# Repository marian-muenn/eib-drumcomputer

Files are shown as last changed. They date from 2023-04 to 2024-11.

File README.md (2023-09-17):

# EIB Drumcomputer

## Projektstruktur
~~~
Das Projekt ist wie folgt strukturiert:
  ./3d/                                                 Dateien für den 3D-Druck
  ./3d/abstandshalter_stromversorgung/                  Abstandhalter zur Montage der Stromversorgung
  ./3d/blindplatte/                                     Blindplatten in diversen Breiten
  ./3d/midi/                                            Frontplatte des MIDI-Interface-Moduls
  ./3d/modul-2-poti/                                    Frontplatte für Drummodule mit 2 Potentiometern
  ./3d/modul_3_poti/                                    Frontplatte für Drummodule mit 3 Potentiometern
  ./3d/winkel/                                          Winkel zur Platinenmontage
  ./doku/                                               Montageanleitung, Bauteillisten, Datenblätter und Spezifikationen
  ./kicad/                                              Platinenentwürfe
  ./kicad/midi-interface                                Platine des MIDI-Interface-Moduls
  ./kicad/line-out                                      Schaltplan des Line-Out Moduls
  ./kicad/klangerzeugung                                Platine zur Klangerzeugung
  ./ltspice/                                            Simulationen
  ./src                                                 Programmcode
  ./tex                                                 Latex Dokumente (Beleg und Montageanleitung)
~~~

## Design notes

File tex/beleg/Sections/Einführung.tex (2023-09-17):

\section{Einführung}

Dieses Projekt widmet sich der Umsetzung eines Drumcomputers, einem elektronischen Musikinstrument, das die Erzeugung und Steuerung perkussiver Klänge ermöglicht. Ein Drumcomputer bietet die Möglichkeit, individuelle Rhythmen zu generieren und abzuspielen, was beispielsweise als Begleitung für Solokünstler von großem Nutzen ist. Der von uns entwickelte Drumcomputer kombiniert analoge Klangerzeugung mit moderner Digitaltechnologie, die eine Steuerung der Klänge über einen Computer ermöglicht. Das Projekt beinhaltet Themen der Digitalen Datenkommunikation, und der Analogen Schaltungstechnik.

Die Grundlage für die Klangerzeugung dieses Projekts beruht auf den Anfängen der elektronischen Musik in den 1970er und 80er Jahren. Es werden insgesamt acht verschiedene Klänge erzeugt, die mithilfe analoger Schwingkreise realisiert werden: Bassdrum (Große Trommel), zwei Snaredrums (Schnarrtrommeln), Cymbal (Becken), Clave (Klanghölzer), Maracas (Rumba-Rasseln) und zwei Congas (lateinamerikanische Trommeln). Diese Klänge können entweder einzeln über einen Taster abgespielt oder vom Mikrocontroller gesteuert werden. Der Mikrocontroller empfängt Signale über die MIDI-Schnittstelle und nutzt diese zur Steuerung der Klänge. MIDI ist der \enquote{Industriestandard für den Austausch musikalischer Steuerinformationen zwischen elektronischen Instrumenten} \cite{wiki_midi} und ermöglicht die Integration der Klänge in die Struktur anderer elektronischer Klangsysteme.

Das Gerät ist im Eurorack-Format konzipiert, um eine nahtlose Integration zu gewährleisten. Eurorack ist ein standardisiertes Format für den Bau von Modulen für modulare Synthesizer. Im folgenden Abschnitt wird eine kurze Einführung in modulare Synthesizer gegeben, um das Gesamtprojekt besser zu verstehen und den Kontext zu erläutern.

\subsection{Einführung modularer Synthesizer}

\begin{figure}[H]
    \centering
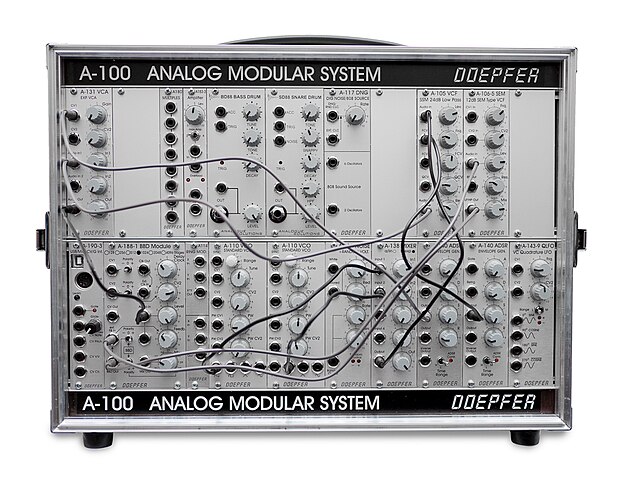
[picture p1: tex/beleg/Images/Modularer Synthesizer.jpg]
    
    \caption[Modularer Synthesizer]{Modularer Synthesizer \cite{wiki_eurorack}}
    \label{fig:Modularer Synthesizer}
\end{figure}

Modulare Synthesizer repräsentieren eine Kategorie von elektronischen Musikinstrumenten, die aufgrund ihrer modularen Struktur eine umfassende Kontrolle über die Klanggenerierung ermöglichen. Der Klang, der schließlich über einen Lautsprecher wiedergegeben wird, setzt sich aus vielfältigen Komponenten zusammen, die in einzelne Module unterteilt sind. 

Die Modularität dieser Synthesizer ermöglicht den Austausch von Modulen sowie die Integration neuer Module. Jedes Modul verfügt über individuelle Parameter, die auch von anderen Modulen beeinflusst werden können. Ein konkretes Beispiel hierfür ist der Voltage-Controlled-Filter (kurz VCF), der durch externe Signale gesteuert werden kann.

Die Verbindung zwischen den einzelnen Modulen erfolgt mithilfe von Kabeln. Jedes Modul verfügt über Ein- und Ausgänge, die den modularen Aufbau ermöglichen und eine flexible Signalverarbeitung ermöglichen.

Das in diesem Projekt entwickelte modulare Drumcomputer-System wurde konzipiert, um die unabhängige Bearbeitung der verschiedenen Klangkomponenten zu ermöglichen. Dadurch können die Klänge separat voneinander verändert und angepasst werden.

Wie bereits in der Einleitung erwähnt, wurde dieses Projekt gemäß dem Eurorack-Standard entwickelt. Das Eurorack stellt eine Stromversorgung für alle Module bereit, wobei die Versorgungsspannungen für die Module bei +12 V, -12 V und +5 V liegen. Der Standard besagt, dass für Trigger Signale 5 V vorgesehen sind. Audio Signale besitzen eine 10 Volt Peak-to-Peak Spannung, für einen besseren Rauschabstand. Zusätzlich sind Pins für Gate- und Steuerspannung (Control Voltage) vorhanden, jedoch werden diese in diesem Projekt nicht verwendet.

%Signale erklären: Gate, Trigger, Control Voltage, Audio
% kurz erläutern, dass auch die bauform der module standardisiert ist

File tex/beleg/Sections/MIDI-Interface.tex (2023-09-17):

\section{MIDI-Interface}
\subsection{Der MIDI Standard}
Die Programmierung des Drumcomputers mit Rythmen soll extern erfolgen. 
Dadurch können bestehende Soft- und Hardware genutzt werden und die Interoperabilität mit anderem Musikequipment ist gegeben.

Dazu wird der Industriestandard MIDI (Music Instrument Digital Interface) genutzt.
Der MIDI-Standard entstand in den 80ger Jahren um Klangerzeuger wie Synthesizer, Keyboards und Drumcomputer sowie Steuergeräte wie Tastaturen miteinander kommunizieren zu lassen.

Auf diese Weise können mit einer Tastatur mehrere Klangerzeuger (Expander) angesprochen werden, was eine erhebliche Kosten und Raumersparnis für Studios und Musiker zur Folge hatte.

Verschiedenste Parameter wie Note, Anschlaggeschwindigkeit, Pedalsignale aber auch allgemeine Kontrollsignale können über MIDI übertragen werden. Aber auch Regleränderungen an einem Klangerzeuger können über MIDI aufgezeichnet und in einem Sequencer oder Computerprogramm wiedergegeben werden.
MIDI verfügt über 16 Kanäle, sodass bis zu 16 mit MIDI-Kabeln verkette Geräte einzeln angesprochen werden können.

Mit dem Aufkommen von Computerprogrammen zur Musikproduktion hielt MIDI auch erstmals Einzug in die Computerwelt. Mithilfe von sogenannten Systemexklusiven Midi-Befehlen können Instrumentenhersteller auch Firmwareupdates über MIDI implementieren.

\subsection{Elektrische Spezifikationen}
Die MIDI Übertragung erfolgt über zweiadrige Leiter mit 5-Pol DIN-Steckverbindern.

Die Datenübertragung wird dabei über eine Stromschleife mit 5mA ausgeführt.
Da Masseschelifen in der Tontechnik oft zu wahrnehmbaren Brummen führen, stellen diese ein Problem dar.
MIDI verhinder Masseschleifen, indem eingehende MIDI-Signale über einen Optokoppler isoliert werden.

Optokoppler sind Bauteile, die eine LED, einen Fotowiderstand und häufig auch einen Transistor in einem Gehäuse vereinen.
In einer Schaltung kann dann mit einem Stromkreis die LED Betrieben werden, in einem Zweiten Stromkreis wird ein proportionales, invertiertes Signal durch Fotowiderstand und Transistor erzeugt. So kann eine Signal zwischen zwei galvanisch getrennten Stromkreisen übertragen werden.

Optional besteht die Möglichkeit, das Signal über einen MIDI-Thru Ausgang an ein weiteres Gerät durchzuschleifen. Dazu wird eine zweite 5 mA Stromschleife hinter dem Optokoppler implementiert und über eine weitere DIN-Buchse ausgegeben.
Auf diese Weise lassen sich bis zu 16 Geräte verketten.
In Abbildung (\ref{fig:schaltplan-midi-inout}) ist die gebräuchliche MIDI-Eingangsschaltung gemäß Spezifikation dargestellt.
\begin{figure}[h]
    \centering
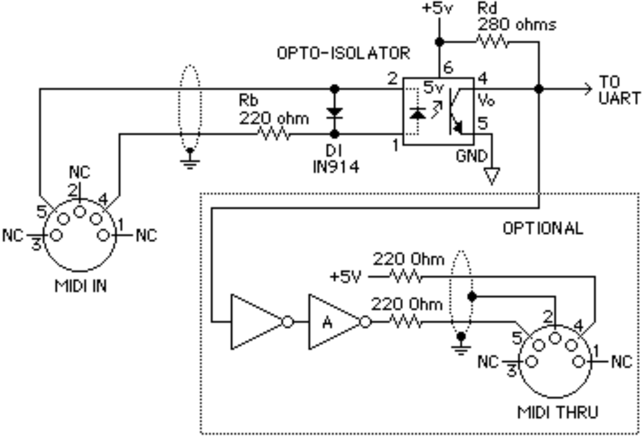
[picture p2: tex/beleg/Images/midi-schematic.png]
    
    \caption{Schaltplan MIDI Eingang \cite[S. 2]{midi}}
    \label{fig:schaltplan-midi-inout}
\end{figure}

Rb dient zur Begrenzung des Stroms, D1 als Schutz vor Verpolung.
Als Optokoppler kommt ein 6n138 zum Einsatz. Rd ist dabei der Pullupwiderstand für das Ausgangssignal. Um das 31250 Baud-Signal trotz des intrinsisch langsamen Optokopplers ohne Verlust der Signalintegrität übertragen zu können, wird ein relativ geringer Pullupwiderstand von 280 Ohm verbaut.

\subsection{MIDI-Befehle}

Ein MIDI Befehl setzt sich aus 3 über eine serielle Verbindung übertragenen Bytes zusammen.
Im ersten Byte wird ein Statuscode übertragen, Bytes 2 und 3 enthalten Daten.
Statusbytes und Datenbytes lassen sich auch anhand des MSB unterscheiden. Bei Statusbytes ist das Most-Significant-Bit auf 1 gesetzt, bei Datenbytes auf 0.
In Tabelle (\ref{table:midi-commands}) sind einige der MIDI-Befehle aufgeschlüsselt.

\ctable[
  maxwidth=\linewidth,
  caption=Midi Befehlsübersicht \cite{wiki_midi},\cite{midi},
  botcap,
  pos=h,
  label=table:midi-commands
  ]{llllX}{}{%
  \FL
Status  & Byte1 & Byte 2    & Aktion        & Beschreibung\ML
0x9n    & 0xkk  & 0xvv      & Note On     & Beginnt das Spielen einer Note kk auf Kanal n mit Anschlagdynamik kk\NN
0x8n    & 0xkk  & 0xvv     & Note Off  &   Beendet das Spielen einer Note kk auf Kanal n mit \enquote{Release Velocity} kk\NN
0xBn 	& 0xcc 	& 0xvv 	     & Control Change &	Ändert den Zustand eines Controllers auf Kanal n (Instrumentenspzifisch) \NN
0xEn 	& 0xvv  & 0xww 	 & Pitch Bending & Ändert die Tonhöhe der gehaltenen Noten, ähnlich wie das Saitenziehen bei einer Gitarre \NN
0xF0…7 	& 0xx 	&           & System exclusive Message & Steuermeldungen, gerätespezifisch, Länge beliebig \NN
\LL}

Um die Datenübertragung zu beschleunigen, darf bei wiederholter Übertragung von Befehlen des gleichen Typs das Statusbyte ausgelassen werden.

Zusätzlich zu den hier genannten Befehlen nutzt MIDI \enquote{Active Sensing}.
Dabei wird im Abstand von 300 ms das Byte \texttt{0b00000001} übertragen.
Wenn diese Übertragung ausbleibt, kann ein lauschendes Gerät einen Ausfall des Übertragungskanals erkennen und das Spielen von Noten beenden.

\subsection{Hardwareentwurf des Midi-Interfaces}
\label{midi-hardwareentwurf}
Um die MIDI-Schnittstelle des Drumcomputers zu implementieren wurde eine Interfacemodul gebaut.
Dieses hat einen MIDI-Eingang sowie 12 Triggersignal-Ausgänge.
Zum Auswerten der Seriellen Midi Kommunikation nutzt das Midi-Modul ein Arduino UNO, das von hinten auf die Platine aufgesteckt wird.

Die Entscheidung für das Arduino fiel, da es bereits vorhanden war, den Anforderungen an die Pin-Anzahl und Systemleistung genügt und der verbaute ATmega328p Microcontroller mit einer Betriebsspannung von 5V läuft. Dadurch können eurorackkompatible Triggersignale ohne Pegelwandler ausgegeben werden.

Für die Eingangsschaltung wurde die Schaltung aus der MIDI-Spezifikation verwendet. Das über den Optokoppler isolierte Signal ist mit dem RX-Pin des Arduinos verbunden.

Zwölf Ausgänge des Mikrocontrollers wurden auf 3.5 mm Mono-Klinkenbuchsen geroutet, damit die Ausgehenden Triggersignale mit Patchkabeln zu die einzelnen Drummodule übertragen werden können.
Dabei besteht die Gefahr, dass mit dem Kabel eine der Betriebsspannungen berührt wird.
Zum Schutz des Microcontrollers wurden daher alle Ausgänge mit 220 Ohm Widerständen gegen Stromspitzen  geschützt.

Schaltpläne und Platinenlayouts finden sich in der beiliegenden Dokumentation.

\subsection{Implementierung der MIDI-Schnittstelle in C}
Die Implementierung des Programmcodes geschah in C, da die Programmierung des ATMega328p in C bereits bekannt war. Teile einer UART-Implementierung lagen aus anderen Lehrveranstaltungen bereits vor, was die Implementierung erleichtert hat.

Der Programmaufbau besteht aus zwei Hauptkomponenten: 
\begin{enumerate}
    \item Einem Zustandsautomaten, der in der Interruptroutine der seriellen Schnittstelle eingehende MIDI-Befehle entgegen nimmt.
    \item Einer periodisch ablaufenden Funktion, die die jeweiligen Ausgänge schaltet.
\end{enumerate}

Der Zustandsautomat der MIDI-Implementierung ist in Abbildung (\ref{fig:sm}) abgebildet.

\begin{figure}[h]
    \centering
    
    \caption{Zustandsautomat der Midi Implementierung}
    \label{fig:sm}
\end{figure}

Da nur Triggersignale generiert werden müssen, ist nur der Note-On Statuscode relevant. Die Ausgänge werden nach 1 ms wieder abgeschaltet, der Note-Off Befehl wird ignoriert.

Das Programm beginnt im Zustand \enquote{ready}.
Beim Empfang eines Note-On-Statuscodes geht der Automat in den Zustand \enquote{note\_on} über.

Beim Eingang des ersten Datenbytes wird in den Zustand \enquote{note\_data1} übergegangen, die über-tragenen Notenwerte werden in einer Variable gespeichert.

Nach der Übertragung des zweiten Datenbytes befindet sich der Automat im Zustand \enquote{note\_data2}.
Der zu schaltende Ausgang wird im Pufferspeicher markiert, die im zweiten Datenbyte übertragenen Velocitydaten sind für den Anwendungfall nicht relevant.

Bei Eingang eines weiteren Datenbytes wird in den Zustand \enquote{note\_data1} übergegangen. Dadurch wird die Übertragung mehrerer Note-On Befehle ohne wiederholung des Status-Bytes ermöglicht.

MIDI-Active-Sense Bytes, die regelmäßig übertragen werden um die Funktion des Datenkanals zu prüfen, werden ignoriert.

Bei Übertragung eines anderen Statusbefehls als Note-On wird in den Zustand \enquote{ready} gewechselt und auf Eingang eines Note-On Befehls gewartet.

In der Hauptschleife der \texttt{main}-Funktion werden die zu schaltenden Ausgänge aktiviert, anschließend wird für eine Millisekunde pausiert. So wird erreicht, dass die Triggersignale für genau eine Millisekunde aktiv sind. 
Dieser Schritt findet in einem Atomic-Block statt, sodass kein Interrupt das Schalten der Ausgänge unterbrechen kann.

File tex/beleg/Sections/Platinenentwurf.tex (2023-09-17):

\section{Platinenentwurf}
In Anbetracht der Tatsache, dass die Realisierung der 8 Klänge aufgrund von 3 verschiedenen Schaltungstypen theoretisch den Einsatz individueller Platinen erfordern würde, wurde ein effizienterer Ansatz gewählt. Anstelle der Produktion von drei separaten Platinen, was mit erheblichen Kosten verbunden wäre, wurden die verschiedenen Platinendesigns integriert, um eine einheitliche Platine zu schaffen, die es ermöglicht, alle individuellen Klänge durch die Anpassung der Bauteilbestückung zu erzeugen.

\begin{figure}[h]
    \centering
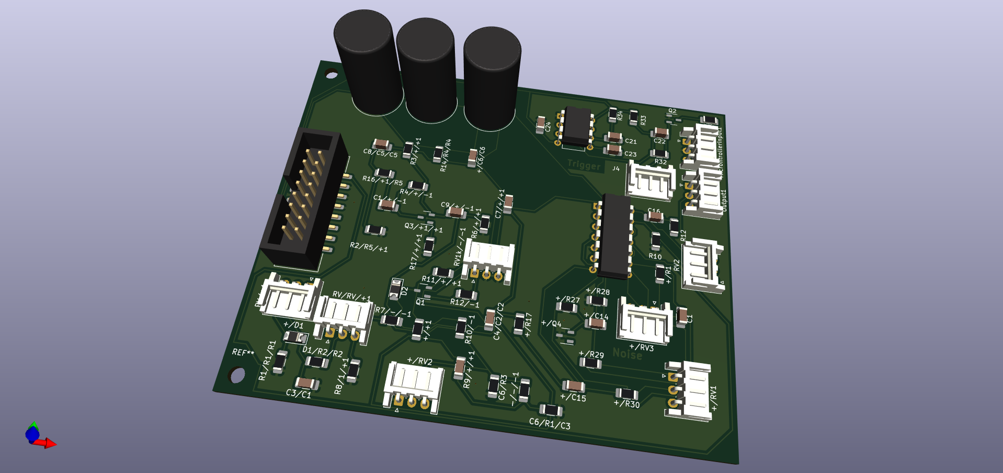
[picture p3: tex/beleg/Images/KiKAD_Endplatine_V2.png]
    
    \caption[Leiterplattenentwurf]{3D-Ansicht der Leiterplatte}
    \label{fig:3D-Ansicht der Leiterplatte}
    \source{KiCad 3D-Ansicht}
\end{figure}

Die Planung und Gestaltung der Platine erfolgte mithilfe von KiCad, einem Open-Source Programm für die Entwicklung von Leiterplattenentwürfen. In Fällen, in denen bereits vorhandene Bauteile wie 3-Pin-Anschlüsse zur Verfügung standen, wurden diese wiederverwendet und entsprechend in das Platinendesign integriert

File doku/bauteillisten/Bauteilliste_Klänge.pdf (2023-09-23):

Bezeichnung Bassdrum | High Bongo High Conga Low Conga | Claves | SnaredrumD Cymbal 1 | Cymbal 2 | maracas | SnareDrum
R1 | 100kΩ | 100kΩ | 100kΩ | 100kΩ | 100kΩ | 100kΩ | 10kΩ | 10kΩ | 10kΩ | 10kΩ
R2 | Diode | Diode | Diode | Diode | Diode | Diode | 1MΩ | 1MΩ | 1MΩ | 1MΩ
R3 | 5kΩ | 5kΩ | 5kΩ | 5kΩ | 5kΩ | 5kΩ | - | - | - | -
R4 | 8.2kΩ | 8.2k | 8.2kΩ | 8.2kΩ | 8.2kΩ | 8.2kΩ | - | - | - | -
R5 | 1MΩ | 1MΩ | 1MΩ | 1MΩ | 1MΩ | 1MΩ | - | - | - | -
R6 | 47kΩ | 27kΩ | 27kΩ | 27kΩ | 27k | 27kΩ | 0Ω | 0Ω | 0Ω | 0Ω
R7 | - | - | - | - | - | - | 470kΩ | 470kΩ | 470kΩ | 470kΩ
R10 | 100Ω | 100Ω | 100Ω | 100Ω | 100Ω | 100Ω | 0Ω | 0Ω | 0Ω | 0Ω
R11 | 22kΩ | 22kΩ | 22kΩ | 22kΩ | 22kΩ | 22kΩ | 56kΩ | 56kΩ | 12k | 20k
R12 | 100kΩ | 100kΩ | 100kΩ | 100kΩ | 39kΩ | 39kΩ | 100kΩ | 100kΩ | 100kΩ | 100kΩ
R13 | - | - | - | - | 56kΩ | 56kΩ | - | - | - | -
R14 | - | - | - | - | 100kΩ | 560kΩ | - | - | - | -
R15 | - | - | - | - | 10kΩ | 10kΩ | - | - | - | -
R16 | - | - | - | - | 330Ω | 2.2kΩ | - | - | - | -
R17 | - | - | - | - | 4.7kΩ | 2.2kΩ | - | - | - | -
R18 | 1kΩ | 1kΩ | 1kΩ | 1kΩ | 1kΩ | 1kΩ | 1kΩ | 1kΩ | 1kΩ | 1kΩ
R19 | 1kΩ | 1kΩ | 1kΩ | 1kΩ | 1kΩ | 1kΩ | 1kΩ | 1kΩ | 1kΩ | 1kΩ
C1 | 10uF | 10uF | 10uF | 10uF | 1uF | 10uF | 180nF | 150nF | 56nF | 56nF
C2 | 68nF | 6.8nF | 6.8nF | 33nF | 1.8nF | 22n | 47nF | 47nF | 10nF | 8.2nF
C3 | 47kΩ | 27kΩ | 27kΩ | 27kΩ | 27k | 27kΩ | - | - | - | -
C4 | 1uF | 1uF | 1uF | 1uF | 1uF | 1uF | - | - | - | -
C5 | 150n | 390nF | 39nF | 82nF | 15nF | 56nF | 1nF | 1nF | 1nF | 1n
C6 | - | - | - | - | - | - | 6.8nF | 6.8nF | 10nF | 3.3nF
C7 | 1uF | 0.47uF | 470nF | 470nF | 1uF | 1uF | 4.7nF | 4.7nF | 4.7nF | 1nF
C8 | - | - | - | - | 1uF | 1uF | - | - | - | -
C9 | - | - | - | - | 8.2nF | 470nF | - | - | - | -
C10 | 1uF | 1uF | 1uF | 1uF | 1uF | 1uF | 1uF | 1uF | 1uF | 1uF
D1 | - | - | - | - | - | - | Diode | Diode | Diode | Diode
D2 | 68nF | 6.8nF | 6.8nF | 33nF | 1.8nF | 22nF | Diode | Diode | Diode | Diode
L1 | - | - | - | - | - | - | 33mH | 33mH | 18mH | 100mH
L2 | - | - | - | - | - | - | - | - | - | 100mH

L3 | - | - | - | - | - | - | - | - | - | 100mH
R21 | - | - | - | - | - | - | 100kΩ | 100kΩ | 100kΩ | 100kΩ
R22 | - | - | - | - | - | - | 100kΩ | 100kΩ | 100kΩ | 100kΩ
R24 | - | - | - | - | - | - | 1kΩ | 1kΩ | 1kΩ | 1kΩ
R25 | - | - | - | - | - | - | 10kΩ | 10kΩ | 10kΩ | 10kΩ
R26 | - | - | - | - | - | - | 1kΩ | 1kΩ | 1kΩ | 1kΩ
C21 | - | - | - | - | - | - | 1uF | 1uF | 1uF | 1uF
C23 | - | - | - | - | - | - | 1uF | 1uF | 1uF | 1uF
R31 | 10kΩ | 10kΩ | 10kΩ | 10kΩ | 10kΩ | 10kΩ | 10kΩ | 10kΩ | 10kΩ | 10kΩ
R32 | 47kΩ | 47kΩ | 47kΩ | 47kΩ | 47kΩ | 47kΩ | 47kΩ | 47kΩ | 47kΩ | 47kΩ
R33 | 220Ω | 220Ω | 220Ω | 220Ω | 220Ω | 220Ω | 220Ω | 220Ω | 220Ω | 220Ω
R34 | 10kΩ | 10kΩ | 10kΩ | 10kΩ | 10kΩ | 10kΩ | 10kΩ | 10kΩ | 10kΩ | 10kΩ
C31 | 100nF | 100nF | 100nF | 100nF | 100nF | 100nF | 100nF | 100nF | 100nF | 100nF
C32 | 10nF | 10nF | 10nF | 10nF | 10nF | 10nF | 10nF | 10nF | 10nF | 10nF
C33 | 10uF | 10uF | 10uF | 10uF | 10uF | 10uF | 10uF | 10uF | 10uF | 10uF
C34 | 100nF | 100nF | 100nF | 100nF | 100nF | 100nF | 100nF | 100nF | 100nF | 100nF
Q1 | NPN | NPN | NPN | NPN | NPN | NPN | NPN | NPN | NPN | NPN
Q2 | - | - | - | - | - | - | NPN | NPN | NPN | NPN
Q3 | NPN | NPN | NPN | NPN | NPN | NPN | NPN | NPN | NPN | NPN
Q4 | - | - | - | - | - | - | NPN | NPN | NPN | NPN
U1 | Ne555 | Ne555 | Ne555 | Ne555 | Ne555 | Ne555 | Ne555 | Ne555 | Ne555 | Ne555
U2 | TL074 | TL074 | TL074 | TL074 | TL074 | TL074 | TL074 | TL074 | TL074 | TL074
RV_Trim | 1kΩ | 1kΩ | 1kΩ | 1kΩ | 1kΩ | 1kΩ | - | - | - | -
RV1 | 10kΩ | 10kΩ | 10kΩ | 10kΩ | 10kΩ | 10kΩ | - | - | - | -
RV2 | 1kΩ | 1kΩ | 1kΩ | 1kΩ | 1kΩ | 1kΩ | 0Ω | 0Ω | 0Ω | 0Ω
RV3 | 50kΩ | 50kΩ | 50kΩ | 50kΩ | 50kΩ | 50kΩ | 50kΩ | 50kΩ | 50kΩ | 50kΩ
RV4 | - | - | - | - | - | - | 10kΩ | 10kΩ | 10kΩ | 10kΩ
Microcontroller Input 3.5mm jack 3.5mm jack 3.5mm jack 3.5mm jack 3.5mm jack 3.5mm jack 3.5mm jack 3.5mm jack 3.5mm jack 3.5mm jack
Output1 | 3.5mm jack 3.5mm jack 3.5mm jack 3.5mm jack 3.5mm jack 3.5mm jack 3.5mm jack 3.5mm jack 3.5mm jack 3.5mm jack
Taster1 | Taster | Taster | Taster | Taster | Taster | Taster | Taster | Taster | Taster | Taster

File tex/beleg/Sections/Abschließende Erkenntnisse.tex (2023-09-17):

\section{Herausforderungen im Projektverlauf}
Während des Projekts traten verschiedene Herausforderungen auf, die im Folgenden zusammenge-
fasst werden:
\begin{description}
\item[Einschränkungen bei der Schaltungssimulation:] Die Erzeugung von Rauschen in der Schal-
tung erfolgt durch die unübliche Nutzung eines Transistors. Dies führte dazu, dass eine
vollständige Simulation der Schaltung nicht möglich war, um deren ordnungsgemäße Funk-
tionsweise zu überprüfen.
\item[Hastige Implementierung eines einstellbaren Tiefpassfilters:] Die Einführung eines einstell-
baren Tiefpassfilters kurz vor Projektabschluss führte zu einer unzureichenden  Überprüfung
der Schaltung, was zu Fehlern führte.
\item[Unzureichende Qualitätskontrolle bei der Zusammenarbeit:] Da jedem Projektmitglied spezifische Aufgabenbereiche zugewiesen wurden, erfolgte eine unzureichende Überprüfung der
Arbeit anderer Teammitglieder. Ein Beispiel hierfür ist die Verwendung eines falschen Foot-
prints für den Transistor, was zu erheblichem Zeitverlust bei der Fehlersuche führte.
\item[Fehleinschätzung der Projektkosten]: Die geschätzten Kosten für das gesamte Projekt wur-
den erheblich unterschätzt, unter anderem aufgrund der ungeprüften Annahme, dass ausreichend Material
in der Hochschule vorhanden sei. Infolgedessen überstiegen die tatsächlichen Projektkosten
die ursprünglichen Schätzungen erheblich. Dieses Problem hätte durch eine gründlichere Vor-
planung vermieden werden können. Dennoch ist anzumerken, dass vergleichbare Produkte, die auf dem Markt erhältlich sind, erheblich kostenintensiver sind als das im Rahmen dieses Projekts entwickelte Gerät.

\end{description}

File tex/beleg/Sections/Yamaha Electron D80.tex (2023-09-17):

\section{Funktionsweise Yamaha Electron D80}
\label{sec:d80}

Im folgenden Abschnitt wird der ursprüngliche Aufbau der Rhythmus-Sektion der Yamaha Electron D80 betrachtet, der für unser Projekt genutzt wurde.

\begin{figure}[H]
    \centering
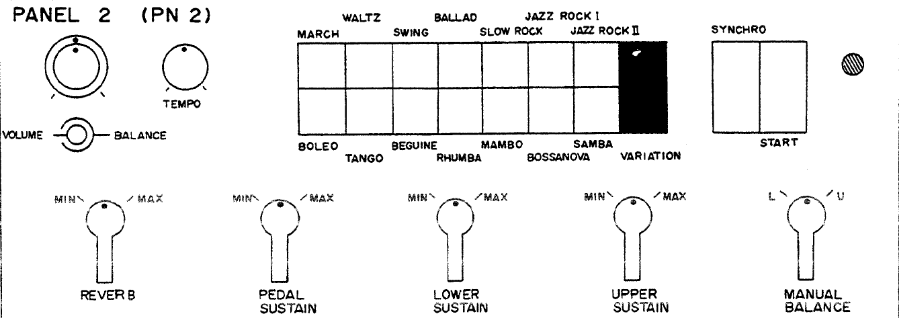
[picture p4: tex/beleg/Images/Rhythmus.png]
    
    \caption[Bedieneroberfläche]{Bedieneroberfläche \cite{ServiceManual}}
    \label{fig:Bediener Oberfläche}
\end{figure}

Auf dem beigefügten Bild ist die Bedienoberfläche der Rhythmus-Sektion zu sehen. Deutlich erkennbar sind die 14 verfügbaren Rhythmusvariationen, die durch das Drücken der entsprechenden Tasten ausgewählt werden können. Beim Betätigen einer dieser Tasten erklingt das zugehörige Rhythmusmuster.

Im Hintergrund wird der Integrierte Schaltkreis des Chips YM22800 getriggert. Dieser dient als logische Schaltung, die die verschiedenen Schaltkreise zur Klangerzeugung in bestimmter Reihenfolge ansteuert. Diese Funktionsweise ist im folgenden Ausschnitt aus dem Schaltplan ersichtlich.

An dieser Stelle sei darauf hingewiesen, dass wir in unserem Projekt die Ansteuerung mithilfe eines programmierbaren Mikrocontrollers realisiert haben, was es uns ermöglicht, beliebige Rhythmusmuster zu realisieren. Eine ausführlichere Erläuterung dazu erfolgt in Abschnitt \ref{midi-hardwareentwurf}.

\begin{figure}[H]
    \centering
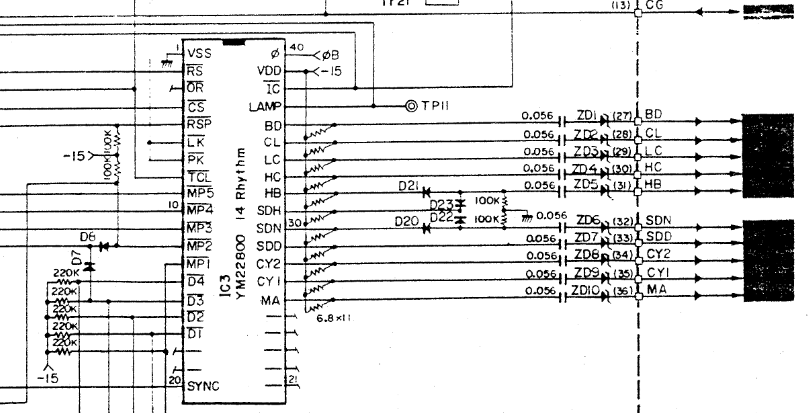
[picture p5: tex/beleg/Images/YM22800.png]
    
    \caption[YM22800]{YM22800 \cite{ServiceManual}}
    
    \label{fig:YM22800}
\end{figure}

Wie zuvor beschrieben, werden die Impulse an die jeweiligen Schaltungen zur Klangerzeugung weitergeleitet. Das nachfolgende Bild dient dazu, die Komplexität zu veranschaulichen, ohne jedoch auf die Details der Schaltung einzugehen, die im nächsten Abschnitt genauer erläutert werden.

\begin{figure}[H]
    \centering
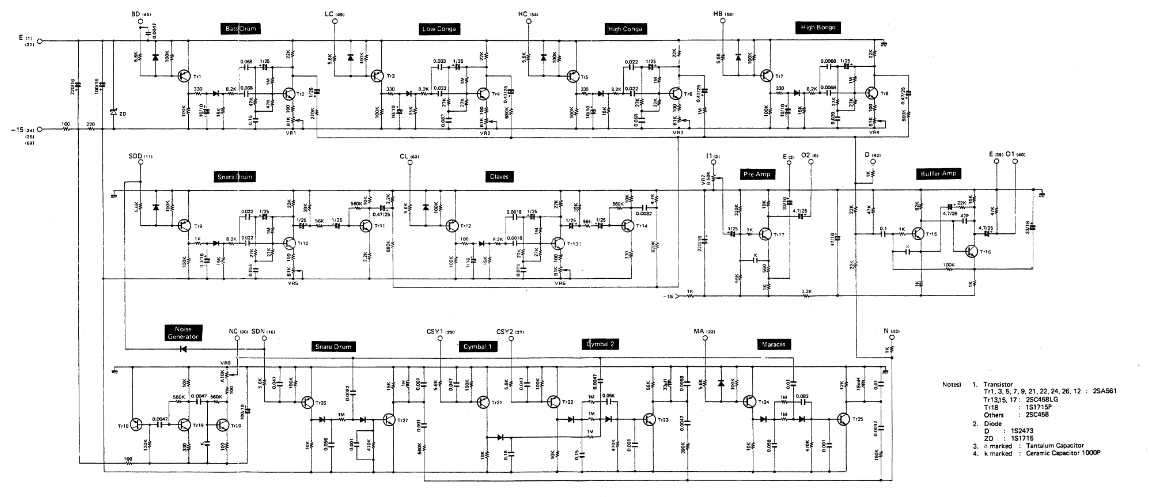
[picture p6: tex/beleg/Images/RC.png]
    
    \caption[Klangerzeugung Schaltplan]{Klangerzeugung Schaltplan \cite{ServiceManual}}
    
    \label{fig:Klangerzeugung Schaltplan}
\end{figure}

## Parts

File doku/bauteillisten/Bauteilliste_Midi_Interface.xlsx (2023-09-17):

Collated Components:
Item | Qty | Reference(s) | Value | LibPart | Footprint | Datasheet | DNP | Sim.Device | Sim.Pins
1 | 1 | C1 | 0.1u | Device:C | Capacitor_SMD:C_1206_3216Metric_Pad1.33x1.80mm_HandSolder | ~
2 | 1 | D1 | 1N914 | Diode:1N914 | Diode_THT:D_DO-41_SOD81_P5.08mm_Vertical_AnodeUp | http://www.vishay.com/docs/85622/1n914.pdf |  | D | 1=K 2=A
3 | 1 | J1 | DIN-5 | Connector:DIN-5_180degree | Connector_PinHeader_2.54mm:PinHeader_1x05_P2.54mm_Vertical | http://www.mouser.com/ds/2/18/40_c091_abd_e-75918.pdf
4 | 1 | J2 | OUT1 | Connector_Audio:AudioJack2_SwitchT | Connector_Audio:Jack_3.5mm_QingPu_WQP-PJ398SM_Vertical_CircularHoles | ~
5 | 1 | J3 | OUT2 | Connector_Audio:AudioJack2_SwitchT | Connector_Audio:Jack_3.5mm_QingPu_WQP-PJ398SM_Vertical_CircularHoles | ~
6 | 1 | J4 | OUT3 | Connector_Audio:AudioJack2_SwitchT | Connector_Audio:Jack_3.5mm_QingPu_WQP-PJ398SM_Vertical_CircularHoles | ~
7 | 1 | J5 | OUT4 | Connector_Audio:AudioJack2_SwitchT | Connector_Audio:Jack_3.5mm_QingPu_WQP-PJ398SM_Vertical_CircularHoles | ~
8 | 1 | J6 | OUT5 | Connector_Audio:AudioJack2_SwitchT | Connector_Audio:Jack_3.5mm_QingPu_WQP-PJ398SM_Vertical_CircularHoles | ~
9 | 1 | J7 | OUT6 | Connector_Audio:AudioJack2_SwitchT | Connector_Audio:Jack_3.5mm_QingPu_WQP-PJ398SM_Vertical_CircularHoles | ~
10 | 1 | J8 | OUT7 | Connector_Audio:AudioJack2_SwitchT | Connector_Audio:Jack_3.5mm_QingPu_WQP-PJ398SM_Vertical_CircularHoles | ~
11 | 1 | J9 | OUT8 | Connector_Audio:AudioJack2_SwitchT | Connector_Audio:Jack_3.5mm_QingPu_WQP-PJ398SM_Vertical_CircularHoles | ~
12 | 1 | J10 | OUT9 | Connector_Audio:AudioJack2_SwitchT | Connector_Audio:Jack_3.5mm_QingPu_WQP-PJ398SM_Vertical_CircularHoles | ~
13 | 1 | J11 | OUT10 | Connector_Audio:AudioJack2_SwitchT | Connector_Audio:Jack_3.5mm_QingPu_WQP-PJ398SM_Vertical_CircularHoles | ~
14 | 1 | J12 | OUT11 | Connector_Audio:AudioJack2_SwitchT | Connector_Audio:Jack_3.5mm_QingPu_WQP-PJ398SM_Vertical_CircularHoles | ~
15 | 1 | J13 | OUT12 | Connector_Audio:AudioJack2_SwitchT | Connector_Audio:Jack_3.5mm_QingPu_WQP-PJ398SM_Vertical_CircularHoles | ~
16 | 1 | J14 | Conn_02x08_Odd_Even | Connector_Generic:Conn_02x08_Odd_Even | Connector_IDC:IDC-Header_2x08_P2.54mm_Vertical | ~
17 | 1 | JP1 | Jumper_Programming | Jumper:Jumper_2_Bridged | Connector_PinHeader_2.54mm:PinHeader_1x02_P2.54mm_Vertical | ~
18 | 1 | R1 | 560R | Device:R | Resistor_SMD:R_1206_3216Metric_Pad1.30x1.75mm_HandSolder | ~
19 | 1 | R2 | 220R | Device:R | Resistor_SMD:R_1206_3216Metric_Pad1.30x1.75mm_HandSolder | ~
20 | 12 | R3, R4, R5, R6, R7, R8, R9, R10, R11, R12, R13, R14 | 270R | Device:R | Resistor_SMD:R_1206_3216Metric_Pad1.30x1.75mm_HandSolder | ~
21 | 1 | U2 | 6N138 | Isolator:6N138 | Package_DIP:DIP-8_W7.62mm | https://optoelectronics.liteon.com/upload/download/DS70-2008-0032/6N135-L%206N136-L%20series.pdf
22 | 1 | XA1 | Arduino_Uno_R3_SMD_Shield | arduino:Arduino_Uno_R3_SMD_Shield | arduino:Arduino_Uno_R3_Shield | https://docs.arduino.cc/hardware/uno-rev3-smd

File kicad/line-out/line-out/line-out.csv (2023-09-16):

Source: | C:\Users\tjori\Documents\GitHub\eib-drumcomputer\kicad\line-out\line-out\line-out.kicad_sch
Date: | 16.09.2023 18:15:53
Tool: | Eeschema 7.0.2
Generator: | C:\Program Files\KiCad\7.0\bin\scripting\plugins/bom_csv_grouped_by_value.py
Component Count: | 17
Collated Components:
Item | Qty | Reference(s) | Value | LibPart | Footprint | Datasheet | DNP
1 | 4 | C1, C2, C3, C4 | 470nF | Device:C |  | ~
2 | 1 | J1 | Input 1 | Connector_Generic:Conn_01x02 |  | ~
3 | 1 | J2 | Input 2 | Connector_Generic:Conn_01x02 |  | ~
4 | 1 | J3 | Output1 | Connector_Generic:Conn_01x02 |  | ~
5 | 1 | J4 | Output2 | Connector_Generic:Conn_01x02 |  | ~
6 | 2 | R1, R3 | 3k6 | Device:R |  | ~
7 | 2 | R2, R4 | 10k | Device:R |  | ~
8 | 4 | R5, R6, R7, R8 | 470k | Device:R |  | ~
9 | 1 | U1 | TL074 | Amplifier_Operational:TL074 |  | http://www.ti.com/lit/ds/symlink/tl071.pdf

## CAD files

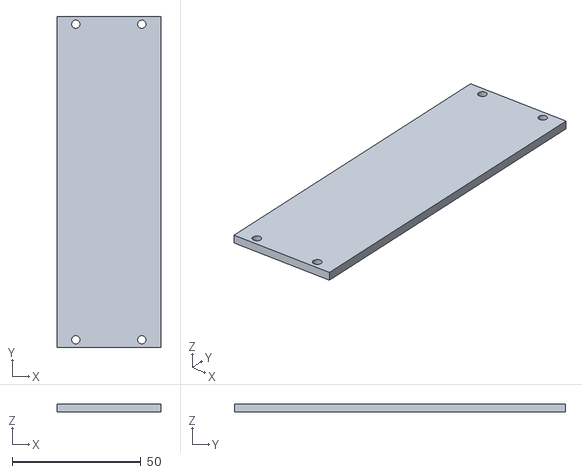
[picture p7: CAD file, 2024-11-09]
3d/blindplatte/blindplatte_8te.stl
40.5 x 128.5 x 3.00

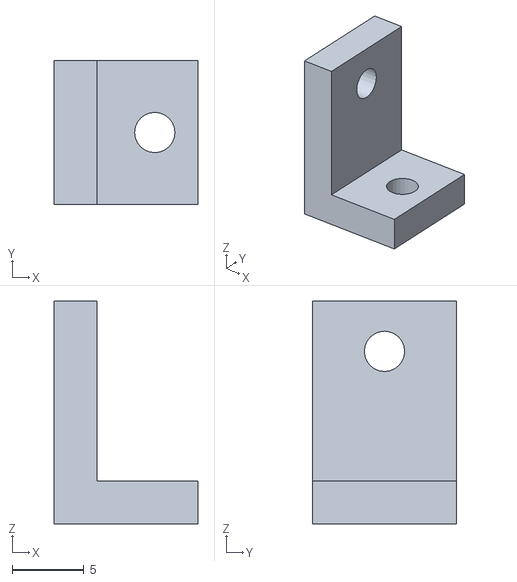
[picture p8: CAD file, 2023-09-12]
3d/winkel/winkel_platinenmontage.stl
10.0 x 10.0 x 15.5

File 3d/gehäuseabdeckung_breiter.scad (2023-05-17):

TE=5.08;
WIDTH= 21.5  * TE;
HEIGHT=132;
THICKNESS=10;
EURORACK_HEIGHT=128.5;

COMB_MARGIN = 8;

// Mounting Hole Offset from the top / bottom edge
HOLE_OFFSET_Y = 3 + ( HEIGHT - EURORACK_HEIGHT)/ 2 ;
// Mounting Hole offset from the sides
HOLE_OFFSET_X = TE;
HOLE_RADIUS = 1.6;
// Number of Facets for the Holes. 
// A reasonably high number should be picked or else holes might end up to small
HOLE_FACETS = 48;

module profile(w){
    PROFILE1 = 8.8;
    PROFILE2 = 4.4;
    PROFILE3 = 80;
    THICKNESS1 = 2.5;
    THICKNESS2 = 1.2;
    THICKNESS3 = 3;
    
    cube([WIDTH, PROFILE1, THICKNESS1]);
    translate([0, PROFILE1, 0])
    cube([WIDTH, PROFILE2, THICKNESS2]);
    translate([0, PROFILE1 + PROFILE2, 0])
    cube([WIDTH, PROFILE3, THICKNESS3]);
    translate([0, HEIGHT, 0])
    mirror([0, 1,0]){
        cube([WIDTH, PROFILE1, THICKNESS1]);
        translate([0, PROFILE1, 0])
        cube([WIDTH, PROFILE2, THICKNESS2]);
        translate([0, PROFILE1 + PROFILE2, 0])
        cube([WIDTH, PROFILE3, THICKNESS3]);
    }

}

module hexagon(l)  {
	circle(d=l, $fn=6);
}

// parametric honeycomb  
module honeycomb(x, y, dia, wall)  {
	smallDia = dia * cos(30);
	projWall = wall * cos(30);

	yStep = smallDia + wall;
	xStep = dia*3/2 + projWall*2;

	difference()  {
		square([x, y]);

		// Note, number of step+1 to ensure the whole surface is covered
		for (yOffset = [0:yStep:y+yStep], xOffset = [0:xStep:x+xStep]) {
			translate([xOffset, yOffset]) {
				hexagon(dia);
			}
			translate([xOffset + dia*3/4 + projWall, yOffset + (smallDia+wall)/2]) {
				hexagon(dia);
			}
		}
	}
}
intersection(){
    difference(){

        union(){
          translate([COMB_MARGIN, COMB_MARGIN, 0])
          linear_extrude(THICKNESS)
            honeycomb(WIDTH - 2 * COMB_MARGIN, HEIGHT - 2*COMB_MARGIN, 4, 2);
          cube([WIDTH, COMB_MARGIN, THICKNESS]);
          cube([COMB_MARGIN, HEIGHT, THICKNESS]);
          translate([WIDTH-COMB_MARGIN,0, 0])
            cube([COMB_MARGIN,HEIGHT, THICKNESS]);
          translate([0, HEIGHT-COMB_MARGIN, 0])
            cube([WIDTH, COMB_MARGIN, THICKNESS]);
        }
        // The four mounting holes
        for (x =[HOLE_OFFSET_X, WIDTH-HOLE_OFFSET_X - 0.5*TE]){
            for (y =[HOLE_OFFSET_Y, HEIGHT-HOLE_OFFSET_Y]){
                color([1,0,0])
                translate([x, y, -0.1]){
                    cylinder(h = THICKNESS+0.2, r=HOLE_RADIUS, center=false, $fn=HOLE_FACETS); 
                };
            }
        };
    };
    profile(WIDTH);
};

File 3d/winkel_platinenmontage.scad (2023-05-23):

THICKNESS = 3;
HOLE_RADIUS = 1.4;
FACETS=24;


difference(){
    cube([10, 10, THICKNESS]);
    translate([10.5-THICKNESS, 5, -0.1]){
        cylinder(r=HOLE_RADIUS, h=THICKNESS + 0.2, center=false, $fn=FACETS);
    }
}
rotate([0,-90,0]){
    difference(){
        cube([10.5 + THICKNESS, 10, THICKNESS]);
        translate([11, 5, -0.1]){
            cylinder(r=HOLE_RADIUS, h=THICKNESS + 0.2, center=false, $fn=FACETS);
        }
    }
}

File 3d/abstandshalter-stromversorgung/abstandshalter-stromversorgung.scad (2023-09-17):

for(i =[0:2]) {
    for (j =[0:2])
        translate([i*20, j*20, 0])
        spacer();
} 

module spacer(){
    difference(){
        cylinder(12, 3, 3, $fn=6);
        translate([0,0,-1])
        cylinder(14, 1.5, 1.5, $fn=8);
    }
}

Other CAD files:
3d/summierer/frontplatte-summierer.stl
3d/blindplatte/blindplatte_6te.stl
3d/blindplatte/blindplatte_6te.scad
3d/blindplatte/blindplatte_8te.scad
3d/gehäuseabdeckungen/gehäuseabdeckung_rückseite.scad
3d/gehäuseabdeckungen/gehäuseabdeckung_rückseite2.scad
3d/gehäuseabdeckungen/gehäuseabdeckung_rückseite3.scad
3d/line-out/frontplatte-line-out.scad
3d/midi/frontplatte-midi.scad
3d/midi/frontplatte-midi_text.scad
3d/modul-2-poti/modul_2_poti.scad
3d/modul-3-poti/modul_3_poti.scad
3d/summierer/frontplatte-summierer.scad
3d/winkel/winkel_platinenmontage.scad

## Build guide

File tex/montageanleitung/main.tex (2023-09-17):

% Author - - Jon Arnt Kårstad, NTNU IMT
\documentclass{article}

% Importing document settings from our file "packages.sty"
\usepackage{packages}

% Beginning of document
\begin{document}

% Inserting title page
\import{./}{title}

% Defining front matter settings 
\frontmatter

% Inserting table of contents
\tableofcontents

% Inserting list of figures & list of tables
\listoffigures

% Defining main matter settings 
\mainmatter

% Introduction explaining this LaTeX-template
\import{./Sections/}{Dokumentation}

% Example section added directly into the main-file

% End of document
\end{document}

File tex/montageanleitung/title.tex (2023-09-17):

% Inspired by title template from ShareLaTeX Learn; Gubert Farnsworth & John Doe
% Edited by Jon Arnt Kårstad, NTNU IMT
% Edited by Linda Vogel, HTWK

\begin{titlepage}
\vbox{ }
\vbox{ }
\begin{center}
% Upper part of the page

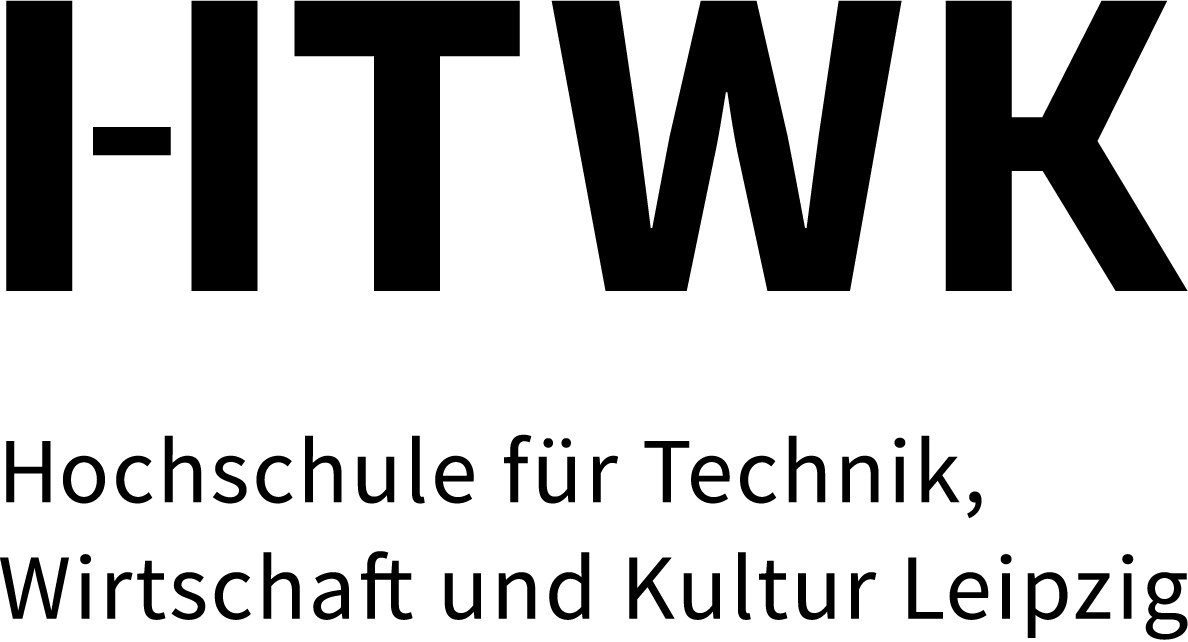
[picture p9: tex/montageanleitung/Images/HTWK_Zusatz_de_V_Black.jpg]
\\[1cm]
%\includegraphics[width=0.40\textwidth,left]{Images/HTWK-Fakultaetszusatz_ing_schwarz_de.png}\\[1cm]

\textsc{\LARGE Fakultät Ingenieurwissenschaften}\\[1.5cm]
\textsc{\Large  E469  - Ausgewählte Themen der Automatisierungstechnik}\\[0.5cm]
\vbox{ }

% Title
\HRule \\[0.4cm]
{ \huge \bfseries Dokumentation – Drumcomputer\\Montageanleitung}\\[0.4cm]
\HRule \\[1.5cm]

\begin{table}[h]
\large
    \centering
    \begin{tabular}{lll}
        \emph{Authoren} & Dima Korschunov & \emph{Matr.Nr.} 79467 \\
                    & Marian Münn & \emph{Matr.Nr.} 80321 \\
                    & Joris Bakker & \emph{Matr.Nr.} 77923 \\
         \emph{Betreuer} & Prof. Dr.-Ing. Jens Jäkel &\\
                         & M. Sc. Marco Braun
    \end{tabular}
\end{table}

\vfill
% Bottom of the page
{\large \today}
\end{center}
\end{titlepage}

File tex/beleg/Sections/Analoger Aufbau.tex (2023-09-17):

\section{Analoger Aufbau}
Im Abschnitt (\ref{sec:d80}) wurde darauf hingewiesen, dass der Drumcomputer aus einem Sequenzer\footnote{ Schaltung die Folgen speichern und beliebig oft wiedergeben kann} und analogen Klangerzeugern besteht. Die Yamaha D80 verwendet im Wesentlichen zwei Schaltungen zur Umsetzung der Klangerzeugung. Im Folgenden werden diese technischen Umsetzungen genauer beschrieben, wobei das Bassdrum- und das Snaredrum-Modul im Fokus stehen, um die beiden Schaltungstypen zu erläutern.

Die vorhandene Schaltung aus der Yamaha Electron D80 modular zu nutzen, wurde sie an den Eurorack-Standard angepasst. Dies beinhaltete wie in der Einführung beschrieben die Änderung der Versorgungsspannung, des Triggers und der Ausgangsspannung. Des Weiteren wurde der Schaltplan um eine manuelle Ansteuerung durch einen Taster erweitert.

\subsection{Manueller Trigger}

Um eine bequeme und direkte Klangeinstellung zu ermöglichen, haben wir die Module mit einem manuellen Trigger erweitert. Hierfür wurde der NE555 Timerbaustein als monostabile Kippstufe und ein Taster genutzt, wie in der Abbildung (\ref{fig:Ne555}) dargestellt.

\begin{figure}[h]
    \centering
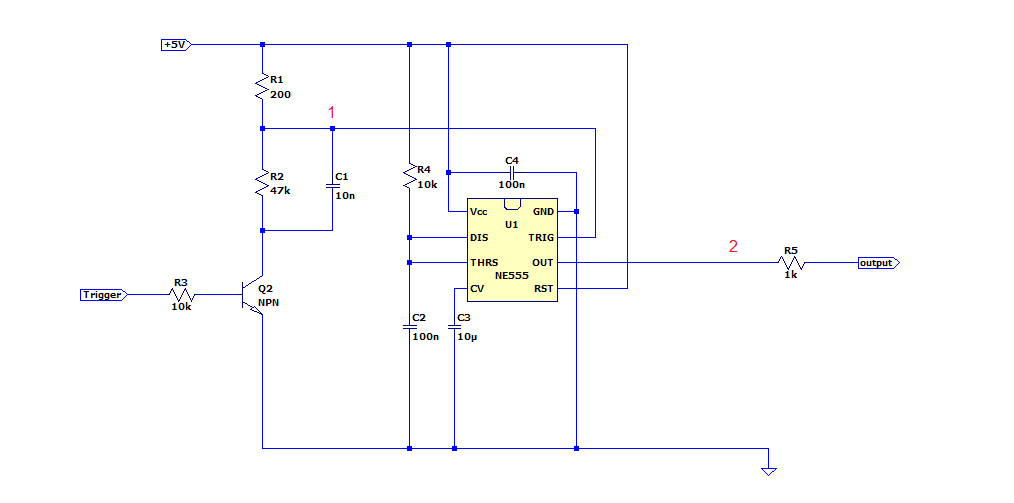
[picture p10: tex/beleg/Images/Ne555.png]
    
    \caption[Ne555]{NE555 Trigger Schaltung}
    \label{fig:Ne555}
\end{figure}

Da die Implementierung eines Tasters in LT Spice nicht möglich ist, wird die Funktionsweise mithilfe des Transistors Q2 erläutert.

Die Schaltung zur Klangerzeugung benötigt einen Triggerimpuls von etwa $1\,\unit{.\milli\second}$ Länge. Um diese Impulsdauer mit dem NE555 Timerbaustein zu erzeugen, muss der Triggereingang des NE555 eine kürzere Impulsdauer als am Ausgang haben. Hierfür wird die Parallelschaltung von R2 und C1 verwendet. Wenn der Transistor leitend wird, aufgrund eines beliebig langen Triggerimpulses, entlädt sich der Kondensator schnell. Durch die Wahl einer sehr kleinen Kapazität wird die Zeitkonstante entsprechend klein, und der Kondensator lädt sich schnell auf die Spannung über R2 wieder auf. Dies erfüllt die Bedingung einer kürzeren Impulsdauer am Eingang.
Die Ausgangsimpulsdauer des NE555 folgt weiterhin der Formel (\ref{eq:Impulsdauer}).

\begin{equation}
   \text{Impulsdauer:}\quad t_w=1.1 \cdot R_4 \cdot C_2
    \label{eq:Impulsdauer}
\end{equation}

Mit den vorliegenden Bauteilwerten erzeugt die Schaltung einen Impuls von $1,1\,\unit{\milli\second}$ Länge, wie im folgenden Simulationsausschnitt des Spannungsverlaufs nachvollzogen werden kann. Dabei repräsentiert der untere Verlauf die Spannung an Punkt 1 und der obere Verlauf die Spannung an Punkt 2 des Schaltplans in Abbildung (\ref{fig:Ne555}).

\begin{figure}[H]
    \centering
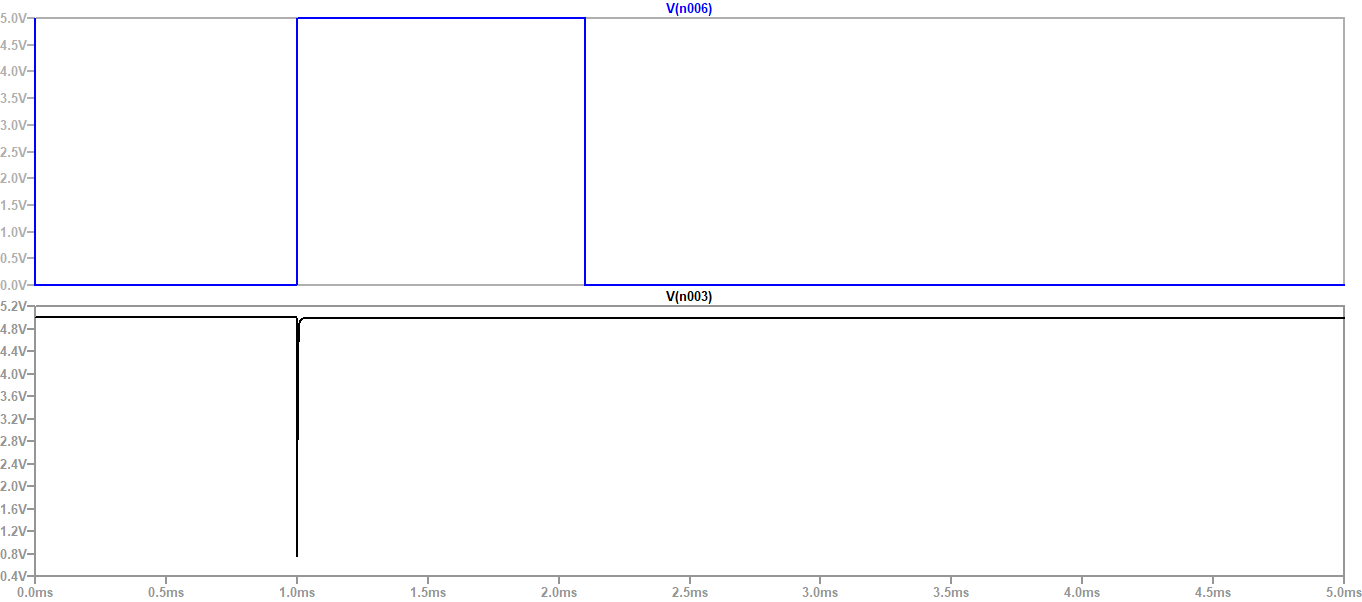
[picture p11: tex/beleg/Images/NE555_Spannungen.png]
    
    \caption[NE555 Spannungswerte]{NE555 Spannungswerte}
    \label{fig:Ne555_Spannung}
\end{figure}

\subsection{Klangerzeugung}

Mit diesem beschriebenen Impuls wird nun die eigentliche Schaltung zur Klangerzeugung ausgelöst. Im Folgenden wird unter Verwendung des Bassdrum-Moduls das allgemeine Prinzip der Klangerzeugung vorgestellt.

\begin{figure}[h]
    \centering
    
    \caption[Bassdrum Schaltplan]{Bassdrum Schaltplan}
    \label{fig:Bassdrum}
\end{figure}

Das Hauptprinzip dieser Schaltung basiert auf der Mitkopplung eines Notchfilters\footnote{besonders schmalbandiger Bandpassfilter} in der Transistorstufe. Bei genauerem Hinsehen erkennt man, dass das Notchfilter durch ein Doppel-T-Filter realisiert wurde. Ein Hinweis darauf ist, dass die Kondensatoren C2 und C4 etwa die halbe Kapazität von C6 haben und die Reihenschaltung aus R3, R4 und R5 den halben Widerstandswert von R6 und R7 besitzt. Dies trifft auch auf das Doppel-T-Filter zu, wie es in der folgenden Abbildung zu sehen ist.
\begin{figure}[H]
    \centering
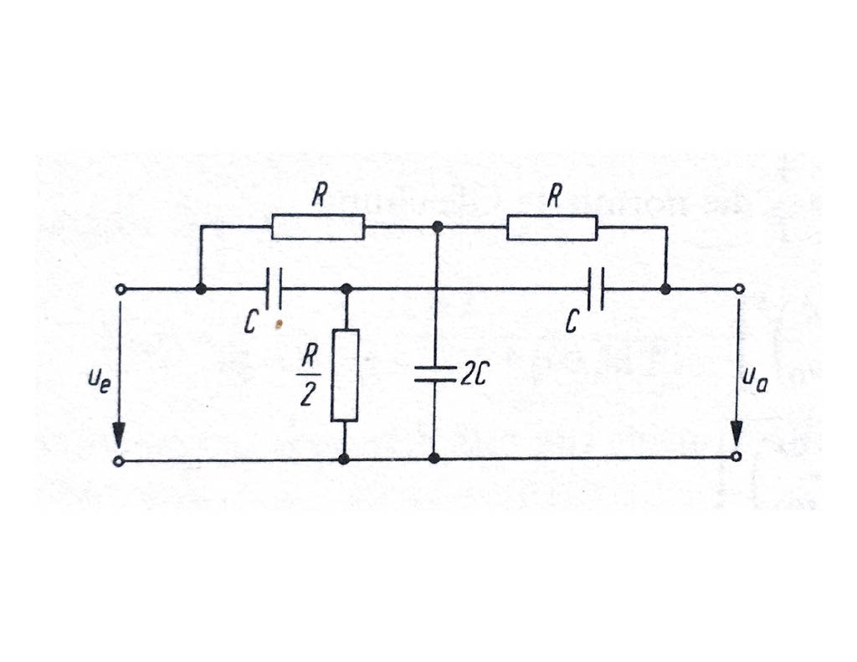
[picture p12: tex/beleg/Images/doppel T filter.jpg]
    
    \caption[Doppel T filter]{Doppel T filter \cite[s.41]{Bystron}}
    \label{fig:doppel T filter}
\end{figure}

Es lässt sich mithilfe der Formel (\ref{eq:Doppel T Filter Resonanzfrequenz}) die Resonanzfrequenz und somit die Tonhöhe der Bassdrum ermitteln. Mit den Bauteilwerten aus der Schaltung ergibt sich eine Resonanzfrequenz von 52,01 Hz.

\begin{equation}
   \text{Resonanzfrequenz} : v_o=\frac{1}{2*\pi*R*C}
    \label{eq:Doppel T Filter Resonanzfrequenz}
\end{equation}

Das Doppel-T-Filter besitzt des Weiteren eine ideale Phasenverschiebung von 180 Grad, wie im nachfolgenden Frequenzgang zu erkennen ist.
\begin{figure}[H]
    \centering
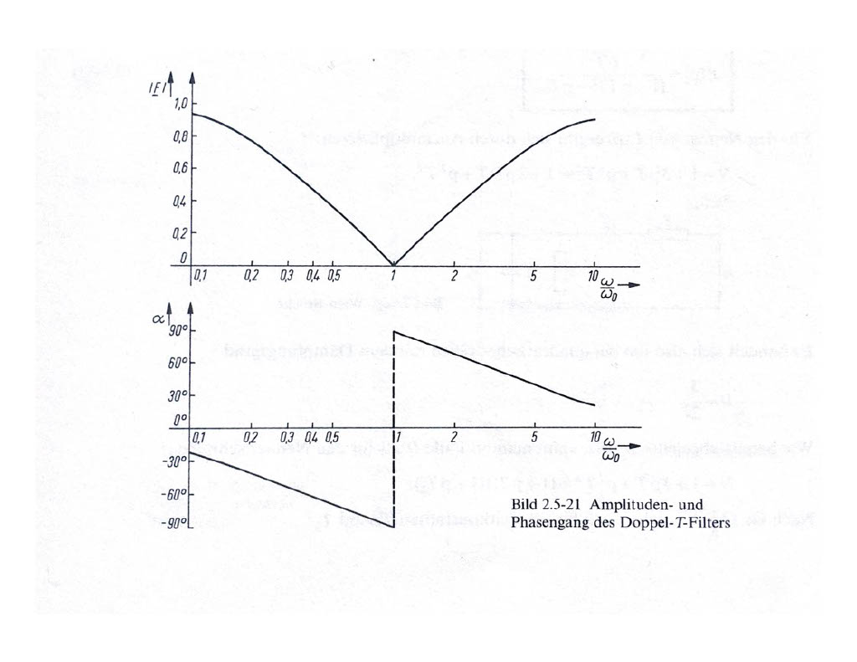
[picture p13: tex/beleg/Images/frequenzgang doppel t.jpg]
    
    \caption[Freuqunzgang Doppel T Filter]{Freuqunzgang Doppel T Filter \cite[s.41]{Bystron}}
    \label{fig:Freuqunzgang Doppel T Filter}
\end{figure}

Im nachfolgenden Bild ist der Frequenzgang zwischen Punkt 1 und Punkt 2 aus Abbildung (\ref{fig:Bassdrum}) zu sehen. Es ist ersichtlich, dass der Phasen- und Amplitudengang mit dem in Abbildung (\ref{eq:Doppel T Filter Resonanzfrequenz}) gezeigten Frequenzgang übereinstimmt, wobei aufgrund der Mitkopplung eine Spiegelung auftritt, die anstelle einer Abschwächung eine Verstärkung der Resonanzfrequenz bewirkt.

\begin{figure}[H]
    \centering
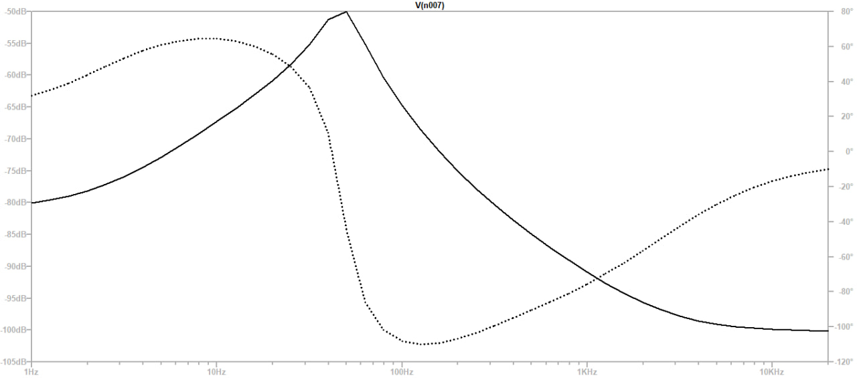
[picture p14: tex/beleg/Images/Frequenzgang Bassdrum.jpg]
    
    \caption[Frequenzgang Bassdrum]{Frequenzgang Bassdrum}
    \label{fig:Frequenzgang Bassdrum}
\end{figure}

Durch die Verschaltung des Transistors erfolgt zusätzlich eine Phasenverschiebung von 180 Grad. Idealerweise würde dies zu einer Gesamtphasenverschiebung von 360 Grad führen, was aufgrund der Mitkopplung in der Transistorstufe dazu führt, dass die Schaltung zu oszillieren beginnt. Durch die gezielte Auswahl der Widerstands- und Kondensatorwerte wird eine Phasenverschiebung erzeugt, die weniger als 360 Grad beträgt. Dies hat zur Folge, dass die Schwingung keine konstante Amplitude aufweist und im Laufe der Zeit abklingt. Die Widerstände R8 bis R11 dienen zur Einstellung des Arbeitspunkts und der Verstärkung, während mit dem Kondensator C5 das Signal wieder Eingekoppelt wird.

Im nachfolgenden Spannungs-Zeit-Verlauf kann nachvollzogen werden, wie die Schwingung aussieht, wobei der Spannungswert nach dem Entkopplungskondensator C6 in LT Spice dargestellt wurde. Hier wird auch deutlich, dass die Schwingung keine konstante Amplitude
aufweist und im Laufe der Zeit abklingt.

\begin{figure}[H]
    \centering
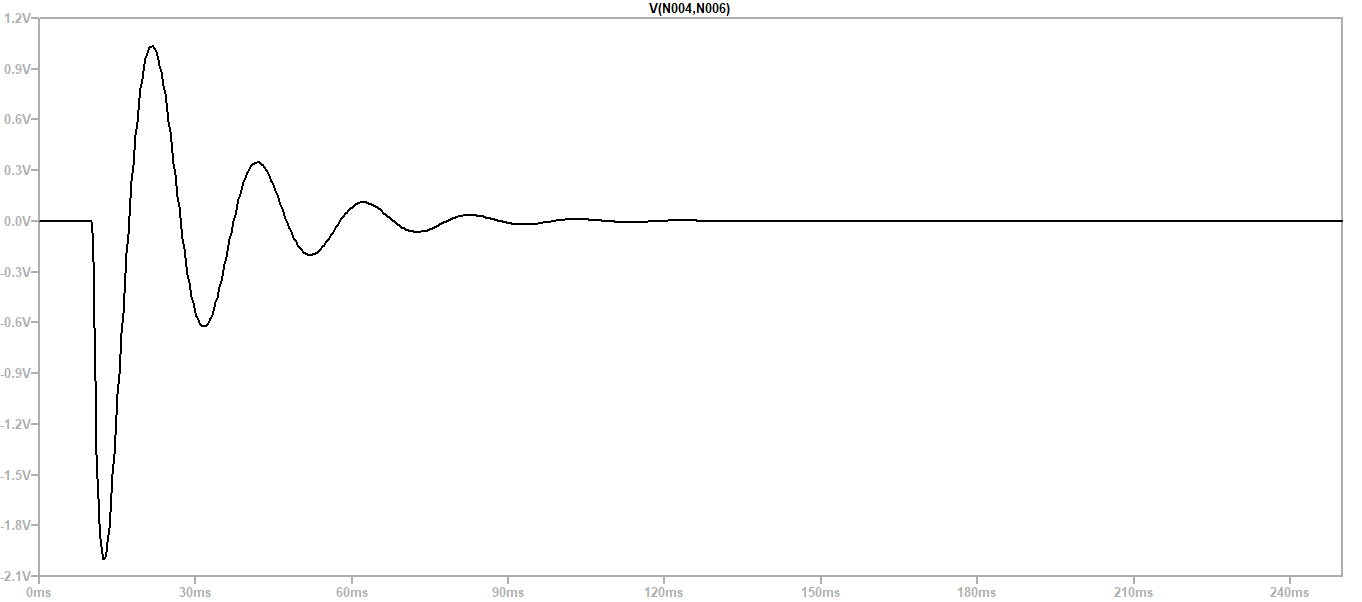
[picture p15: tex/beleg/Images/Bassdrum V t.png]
    
    \caption[Spannungsverlauf Bassdrum]{Spannungsverlauf Bassdrum}
    \label{fig:Spannungsverlauf Bassdrum}
\end{figure}

Nachdem die Bassdrum erläutert wurde, wird nun das Snaredrum-Modul behandelt. Das überarbeitete und angepasste Schaltungsschema ist im folgenden Bild dargestellt.

\begin{figure}[H]
    \centering
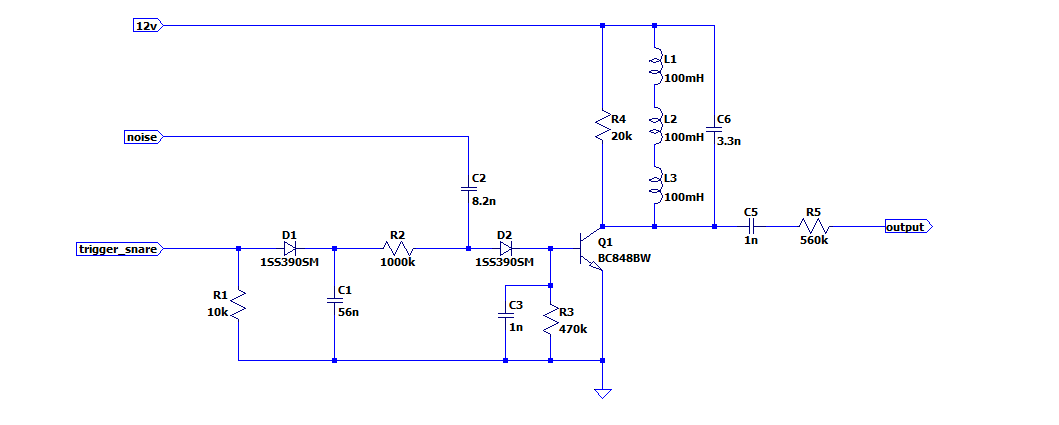
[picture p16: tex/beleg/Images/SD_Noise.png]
    
    \caption[Snaredrum Schaltplan]{Snaredrum Schaltplan\cite{ServiceManual}}
    \label{fig:SD_noise}
\end{figure}
Die Funktionsweise unterscheidet sich von der des Bassdrum-Moduls. Hier erfolgt eine Überlagerung des Triggerimpulses mit Rauschen, welches anschließend verstärkt und mithilfe eines Parallel-Schwingkreises zum Schwingen angeregt wird. Da LT Spice nicht in der Lage ist, die Rauschschaltung zu simulieren, wird der Rauschgenerator anhand des Originalschaltplans erläutert. Im nachfolgenden Bild ist der Schaltplan des Rauschgenerators aus der Yamaha D80 zu sehen.

\begin{figure}[H]
    \centering
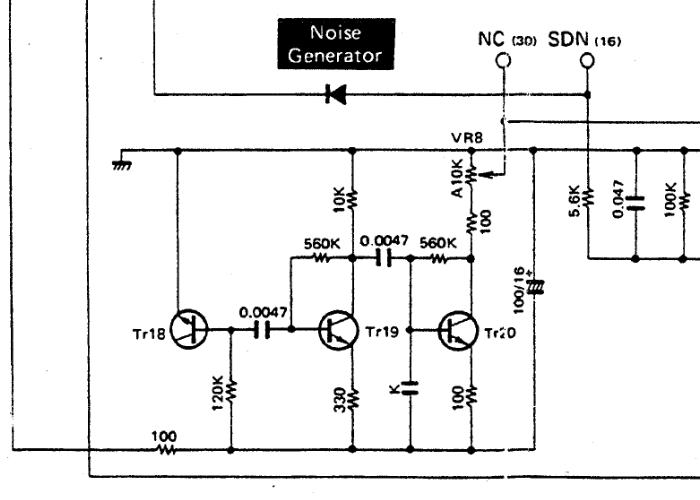
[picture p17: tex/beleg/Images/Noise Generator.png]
    
    \caption[Rauschgenerator]{Rauschgenerator\cite{ServiceManual}}
    \label{fig:Rauschgenerator}
\end{figure}

Das zentrale Element der Rauscherzeugung ist der Transistor Tr18. Bemerkenswert ist, dass aufgrund der Versorgungsspannung von -15 V das höhere Potenzial am Ground liegt und somit ein Stromfluss vom Ground zur Versorgungsspannung stattfindet. Es ist ersichtlich dass die Emitter-Basis-Strecke der Transistors genutzt wird, während der Kollektor-Pin unverbunden bleibt. Wenn die Durchbruchspannung der Emitter-Basis-Strecke von 5 V überschritten wird, erzeugt dies einen zufälligen Stromfluss an der Basis des Transistors. Durch den 120 k$\Omega$ Widerstand wird der zufällige Stromfluss zu einer Spannung welche als weißes Rauschen gemessen werden kann. Der Rest der Schaltung dient der Verstärkung und Filterung des Rauschsignals.

Im folgenden Abschnitt wird die Ausgangsspannung des Snaredrum-Moduls dargestellt. Es ist deutlich erkennbar, dass der Parallel-Schwingkreis nach dem Transistor Q1 den mit Rauschen überlagerten Triggerimpuls zum Schwingen anregt und nach kurzer Zeit aufgrund der Dämpfung durch R4 zum Ausklingen bringt. Mit Hilfe der Thomsonschen Schwingungsgleichung (\ref{eq:Thomsonsche Schwingungsgleichung}) für die Resonanzfrequenz lässt sich die Stimmung der Snaredrum bestimmen. Diese Beträgt 5058 Hz was typisch für eine Snare ist.

\begin{equation}
   \text{Thomsonsche Schwingungsgleichung:} f_o=\frac{1}{2*\pi\sqrt{L*C}}
    \label{eq:Thomsonsche Schwingungsgleichung}
\end{equation}

\begin{figure}[H]
    \centering
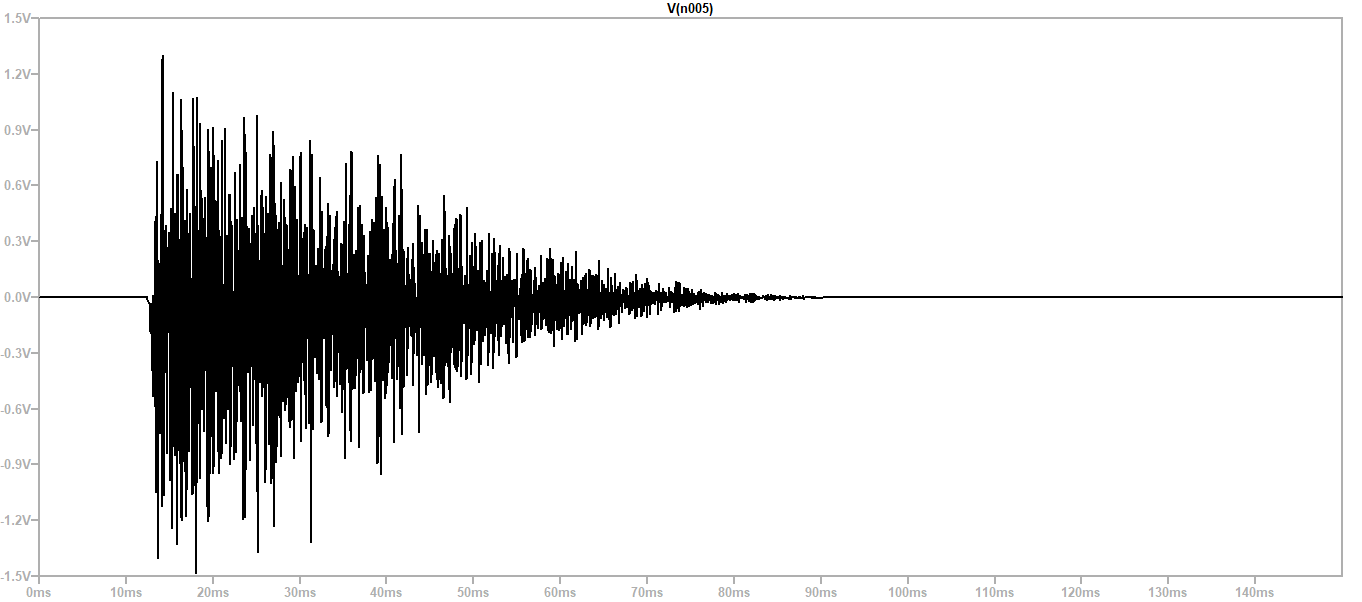
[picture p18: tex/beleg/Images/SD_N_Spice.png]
    
    \caption[Spannungsverlauf Snaredrum]{Spannungsverlauf Snaredrum}
    \label{fig:Spannungsverlauf Snaredrum}
\end{figure}

Wie in Abbildung (\ref{fig:Spannungsverlauf Bassdrum}) und Abbildung (\ref{fig:Spannungsverlauf Snaredrum}) zu sehen ist, beträgt die Ausgangsspannung etwa $5\,\unit{V_{pp}}$. Um den Eurorack-Standard von $10\,\unit{V_{pp}}$ zu erreichen, wurde eine nicht-invertierende Operationsverstärkerschaltung am Ausgang jeder Schaltung hinzugefügt.

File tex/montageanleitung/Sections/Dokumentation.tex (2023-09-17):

\section{Einleitung}
Im Rahmen des Projektes Ausgewählte Themen der Automatisierungstechnik wurde ein modularer Drumcomputer entworfen.
Dieses Dokument enthält eine detaillierte Dokumentation der Montage des Drumcomputers, um den Nachbau zu ermöglichen.

\section{Gehäuse}
\subsection*{Aufbau des Eurorack Gehäuses}
Das Gehäuse wird auf einem gebrauchten Baugruppenträger aufgebaut.
Alternativ sind auch fertige Eurorackgehäuse am Markt erhältlich, sodass dieser Schritt nicht zwingend notwendig ist.

Da der Baugruppenträger an Ober- Unter und Rückseite offen ist, werden Gehäusebdeckungen gefertigt.
Ober- und Unterseite werden mit zwei 1 mm starken Edelstahlblechen abgedeckt.
Diese werden auf 426,5 mm x 128,5 mm zugeschnitten, zur Montage am Baugruppenträger werden an der Vorder- und Hinterkante drei 3 mm Bohrungen gesetzt. Mit M2,5x10 Zylinderkopfschrauben und passenden Muttern wurden die Bleche an der dafür vorgesehenen Bohrungen des Baugruppenträgers befestigt.

Da der Baugruppenträger deutliche Gebrauchsspuren hatte, wurden alle Metallteile lackiert.

Für die Rückseite des Gehäuses werden 4 Abdeckungen mit OpenSCAD entworfen mit dem 3D-Drucker gefertigt.
Diese sind im Verzeichnis \texttt{./3d/gehäuseabdeckungen} zu finden.
Eine der Abdeckungen ist mit einem Ausschnitt zur Montage einer Kaltgerätebuchse versehen.
Die Rückplatten lassen sich mit M2.5x14 Schrauben am Baugruppenträger befestigen.
Die Montage der Kaltgerätebuchse erfolgt mit M3x12 Blechschrauben.
An die Lötösen der Kaltgerätebuchse wurden drei $1,5\,\unit{mm^2}$ Kabel angelötet, die Lötstellen wurden mit Schrumpfschlauch abgedeckt.

\subsection*{Montage des Netzteils}
Als Netzteil wird ein Gerät des Herstellers Mean Well mit Modellnummer \enquote{mw rt-65b} montiert.
Dieses bietet die drei nötigen Betriebsspannungen $+12\,\unit{V}$, $-12\,\unit{V}$ und $+5\,\unit{V}$.

Die Montage erfolgt an der Innenseite der linken Seitenplatte des Baugruppenträgers mit einer M5 und einer M3 Schraube sowie passenden Muttern. Dazu müssen zwei Bohrungen gesetzt werden.

Das so vormontierte Gehäuse ist in Abbildung \ref{fig:baugruppentraeger} abgebildet
\begin{figure}[h]
    \centering
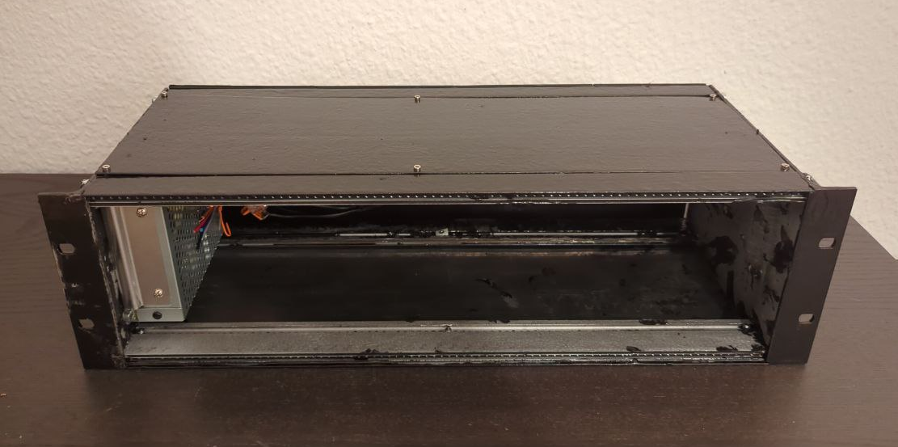
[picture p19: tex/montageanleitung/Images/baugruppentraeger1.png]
    
    \caption{Baugruppenträger mit Netzteil}
    \label{fig:baugruppentraeger}
\end{figure}

\subsection*{Stromverteilung}
Um die Betriebsspannungen für die einzelnen Module verfügbar zu machen, wird eine Platine mit den nötigen IDC-16 Buchsen auf Lochrastermaterial aufgebaut.
Diese verfügt über 8 IDC-16 Buchsen und 4 Schraubterminals zur Verbindung mit dem Netzteil.
Die Platine wird mit 8 3D-Druck-Abstandshaltern (\texttt{./3d/abstandshalter-platinenmontage}) verschraubt, diese wurden mit Epoxidharzkleber an der Rückseite des Gehäuses befestigt.
Die Pinbelegung der IDC-16 Buchse ist der Grafik in Abbildunge \ref{fig:idc16} zu entnehmen. Die Signale Gate und CV sind nicht verbunden.

\begin{figure}[h]
    \centering
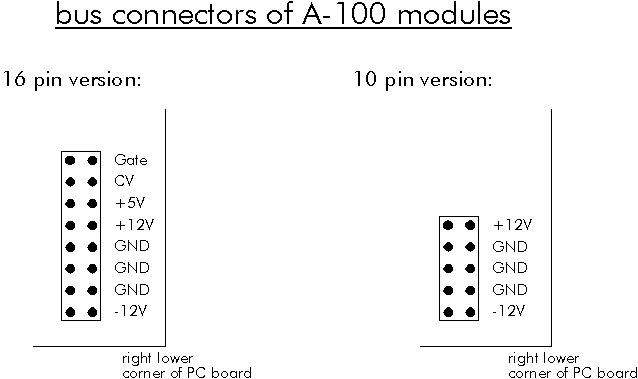
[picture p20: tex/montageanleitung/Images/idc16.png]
    
    \caption[Pinbelegung der IDC-16 Buchsen]{Pinbelegung der IDC-16 Buchsen (links)}
    \label{fig:idc16}
\end{figure}
Die entsprechenden Anschlüsse des Netzteils sind mit den Schraubklemmen der Stromversorgungsplatine zu verbinden.

\section{MIDI-Interface}
Die Platine des MIDI-Interfaces wurde in Kicad entworfen und zur Fertigung in Auftrag gegeben.
Die zur Montage benötigten Bauteile sind im Unterverzeichnis \texttt{./doku/Bauteillisten/} zu finden.
Das Platinenlayout ist in Abbildung (\ref{fig:midi-platine}) abgebildet, der Schaltplan in Abbildung \ref{fig:midi-schaltplan}.
\begin{figure}[h]
    \centering
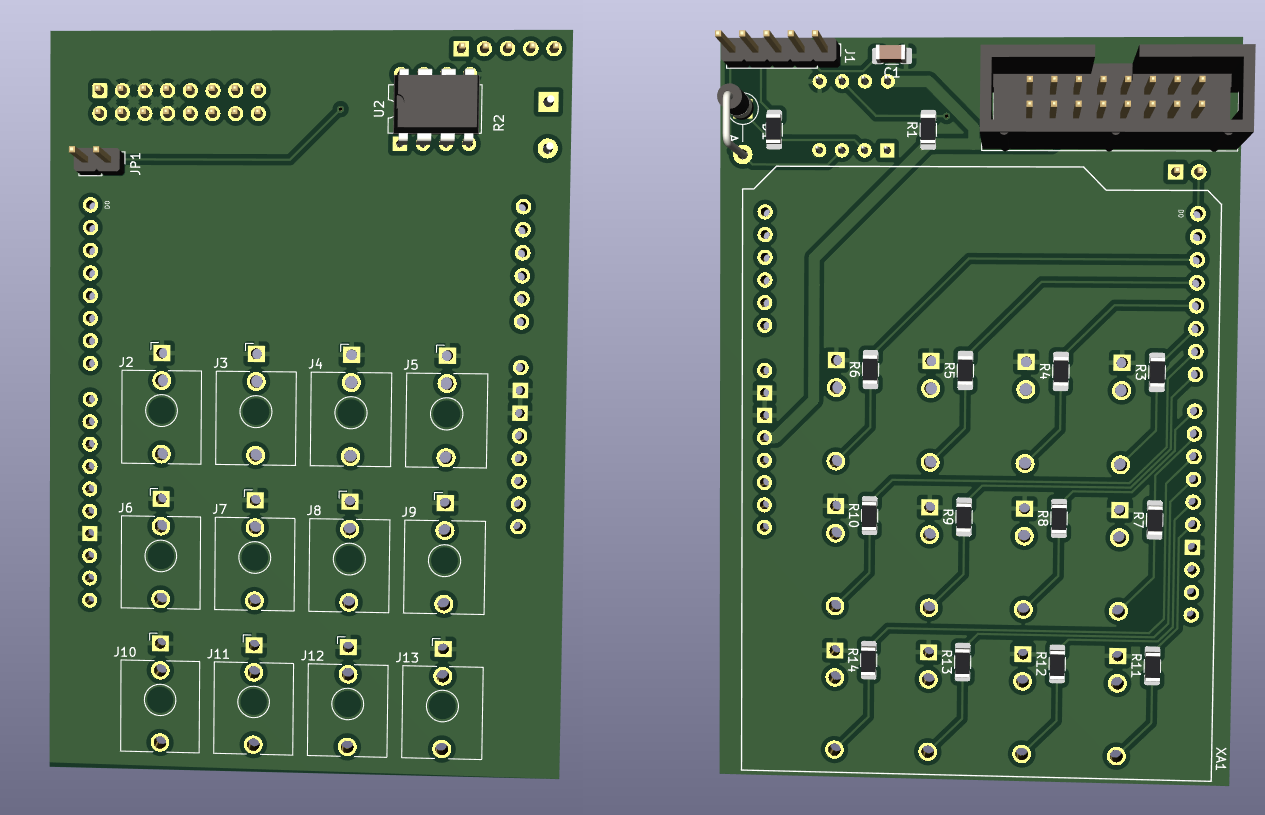
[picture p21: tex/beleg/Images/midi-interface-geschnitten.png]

    \caption{Platinenlayout der MIDI-Platine}
    \label{fig:midi-platine}
\end{figure}
\begin{figure}[h]
    \centering
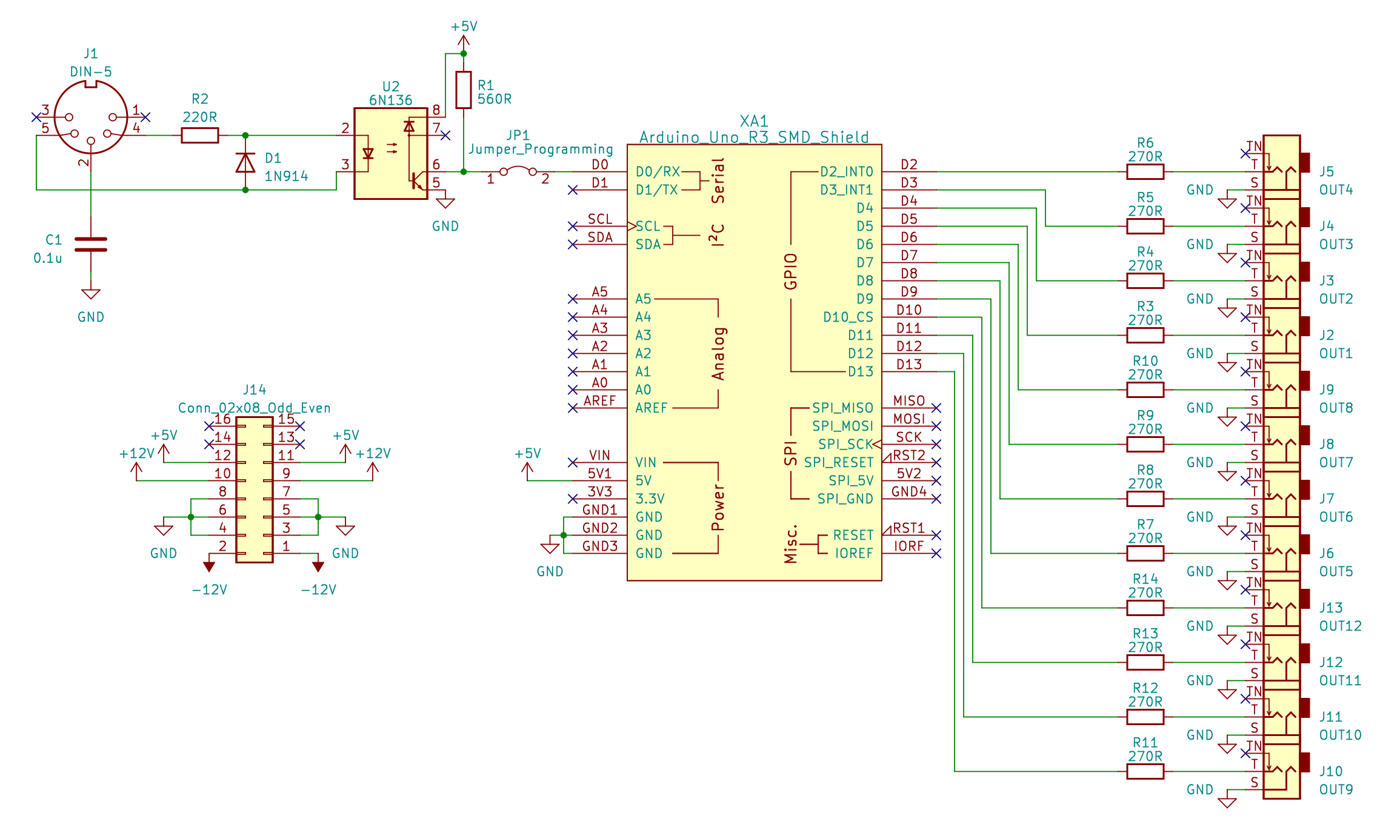
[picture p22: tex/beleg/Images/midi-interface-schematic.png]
    
    \caption{Schaltplan der MIDI-Interface-Platine}
    \label{fig:midi-schaltplan}
\end{figure}

Nach Auflöten der Bauteile muss der Mikrocontroller programmiert werden.
Der Quellcode ist im Verzeichnis \texttt{./src/midi-interface} zu finden.
Mit dem Befehl \texttt{make \&\& make flash} wird der über USB angeschlossene Arduino programmiert. Dazu werden die Programme make, avrdude und avr-gcc benötigt.

Zur Montage der MIDI-Platine wird eine Frontplatte mit dem 3D-Drucker gefertigt.
Diese ist im Verzeichnis \texttt{./3d/midi/} zu finden.
Die Datei \texttt{frontplatte-midi\_text.scad} beeinhaltet eine alternative Version mit beschrifteten Ausgängen. 
Um die Schrift drucken zu können, muss das Filament nach 3 mm Druckhöhe gegen ein andersfarbiges getauscht werden. 
In der Praxis stellte sich der so aufgedruckte Text als wenig widerstandsfähig heraus, weshalb die Beschriftung der Frontplatte mit einem Labeldrucker geschah.

Die Frontplatte kann nun mit den Muttern der Klinkenbuchse mit der Platine verschraubt werden. Das Modul kann mit 4 M2.5 Schrauben an der Vorderseite des Baugruppenträgers verschraubt werden und mit einem Flachbandkabel mit der Stromversorgung verbunden werden.

\section{Klangerzeuger}
Der Aufbau der Klangerzeugung erfordert eine detaillierte Herangehensweise. Insgesamt stehen 10 verschiedene Klänge zur Verfügung, von denen jede ihre eigene individuelle Schaltung aufweist. Eine Analyse zeigte jedoch, dass diese 10 Klänge auf 3 verschiedene Schaltungstypen zurückgeführt werden können. Aus Kostengründen wurden diese 3 Schaltungstypen auf einer Platine zusammengefasst. Diese ist im Ordner \texttt{./kicad/drummodul} zu finden.

Die Bauteilwerte für die einzelnen Platinen sind in der \enquote{Bauteilliste Klänge} im Ordner \\ \texttt{./doku/Bauteillisten} zu finden.

Anmerkungen: In einigen Klängen, darunter Bassdrum, High Bongo, High Conga, Low Conga, Cymbal 1, Cymbal 2, Maracas und Snaredrum Noise, muss eine Drahtbrücke von C7 zu C9  gelegt werden, um Teile der Schaltung zu überbrücken. Im folgenden Foto sieht man welche Stellen das sind. Die Rote Linie ist die Drahtbrücke

\begin{figure}[H]
    \centering
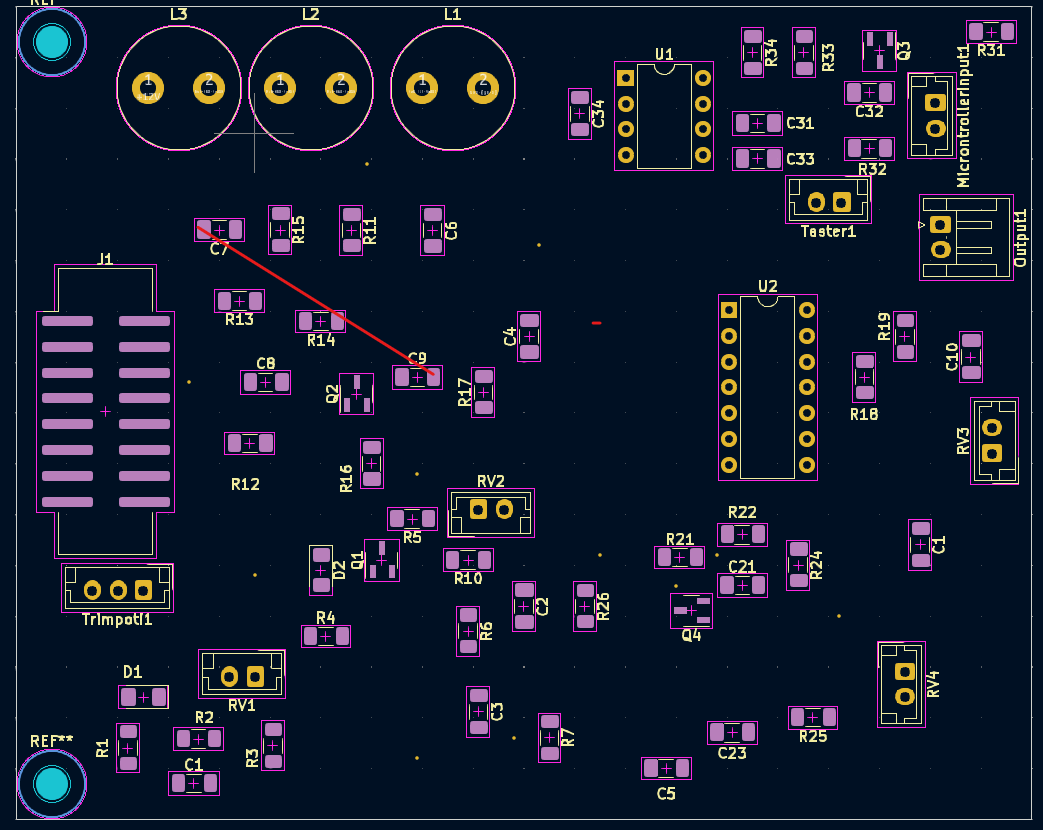
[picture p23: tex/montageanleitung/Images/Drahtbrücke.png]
    
    \caption[Drahtbrücke]{Drahtbrücke}
    \label{fig:Drahtbrücke}
\end{figure}

Je nach Modul werden Frontplatten mit 2 oder 3 Potis benötigt. Diese sind in OpenSCAD entworfen und liegen im Ordner \texttt{./3d/frontplatte-2-potis} bzw. \texttt{./3d/drontplate-3-potis}.

Potentiometer, Taster, Input und Output werden an der Frontplatte angebracht und nicht auf der Platine gelötet. Für die Verbindung stehen 2-polige Stecker vom Typ JST-XH zur Verfügung, die auf die Platine gelötet und dann per Kabel mit den Potentiometern, Tastern und Klinkenbuchsen verbunden werden.
Die Winkel zur Montage der Platine an die Frontplatten liegen in \texttt{./3d/winkel}.
Die Frontplatten werden mit je 2 M2.5x10 Zylinderkopfschrauben und passenden Muttern an den Winkeln befestigt, die Montage der Platine an den Winkeln erfolgt ebenfalls mit 2 M2,5x10 Schrauben.

Ein vollständig montiertes Modul mit Frontplatte ist im folgenden Bild zu erkennen:
\begin{figure}[H]
    \centering
    
    \caption[Zusammengebautes Modul]{Zusammengebautes Modul}
    \label{fig:Zusammengebautes Modul}
\end{figure}
\section{Summierer und Line-Out}
Um die einzelnen Signale der Klangerzeuger zu Mischen und den Eurorackpegel einem überlichen Line-Out Pegel anzupassen wurden zwei weitere Module angefertigt.
Die Module basieren auf einem invertierenden Summierverstärker bzw. einem invertierenden Verstärker.
Die Schaltpläne dazu sind in \texttt{kicad/line-out} und \texttt{kicad/summierer} zu finden.
Der Platinenaufbau erfolgt auf Lochrasterplatinen.
Die dazugehörigen Frontplatten sind in \texttt{./3d/summierer} und \texttt{./3d/line-out} zu finden. Die Montage erfolgt mit den Winkeln aus \texttt{./3d/winkel}

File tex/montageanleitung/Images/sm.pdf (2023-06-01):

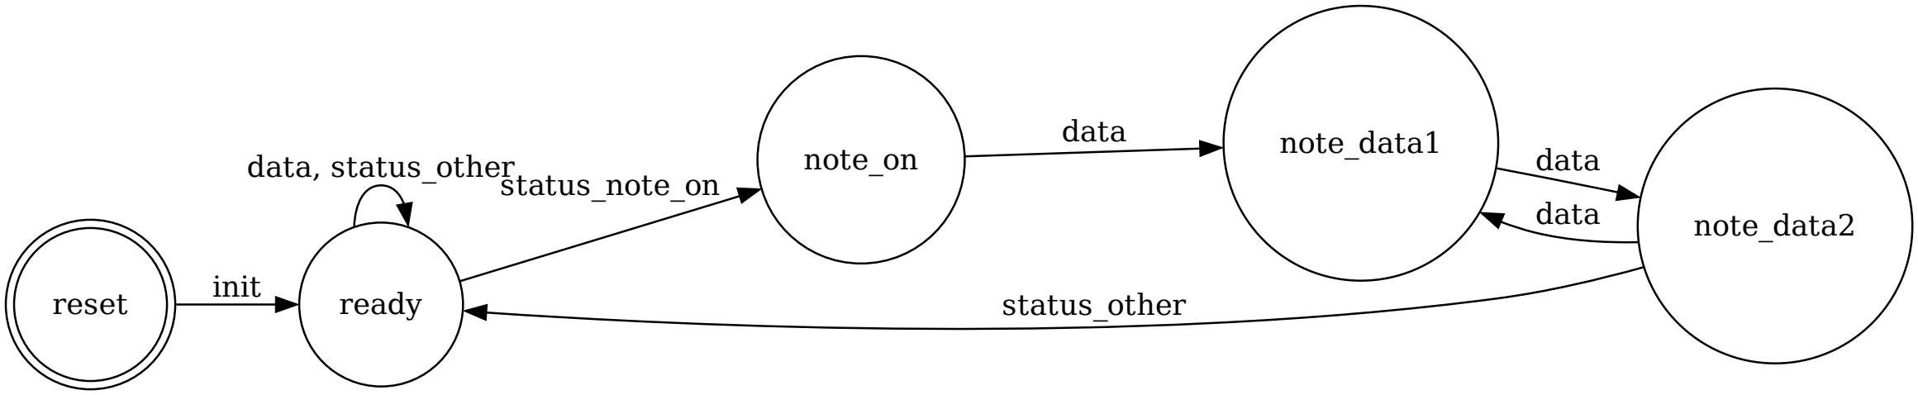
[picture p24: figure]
reset; ready init; data, status_other; note_on status_note_on; note_data1 data; note_data2; data; status_other

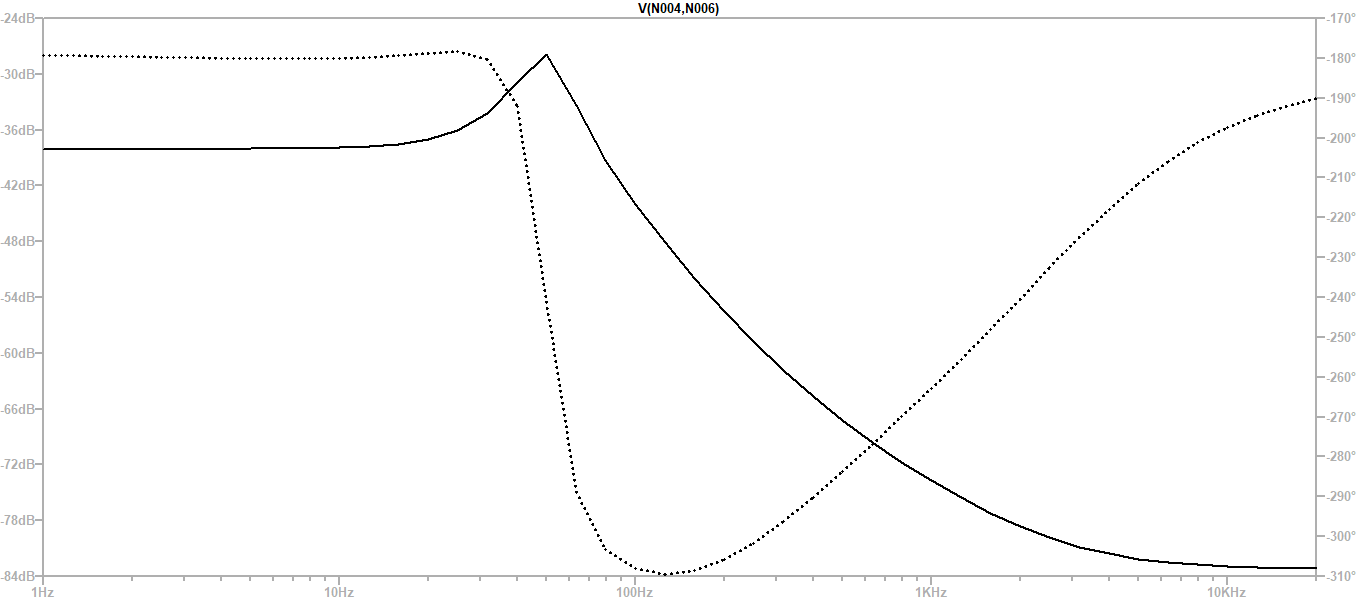
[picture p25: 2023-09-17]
tex/montageanleitung/Images/Frequenzgang Bassdrum.png

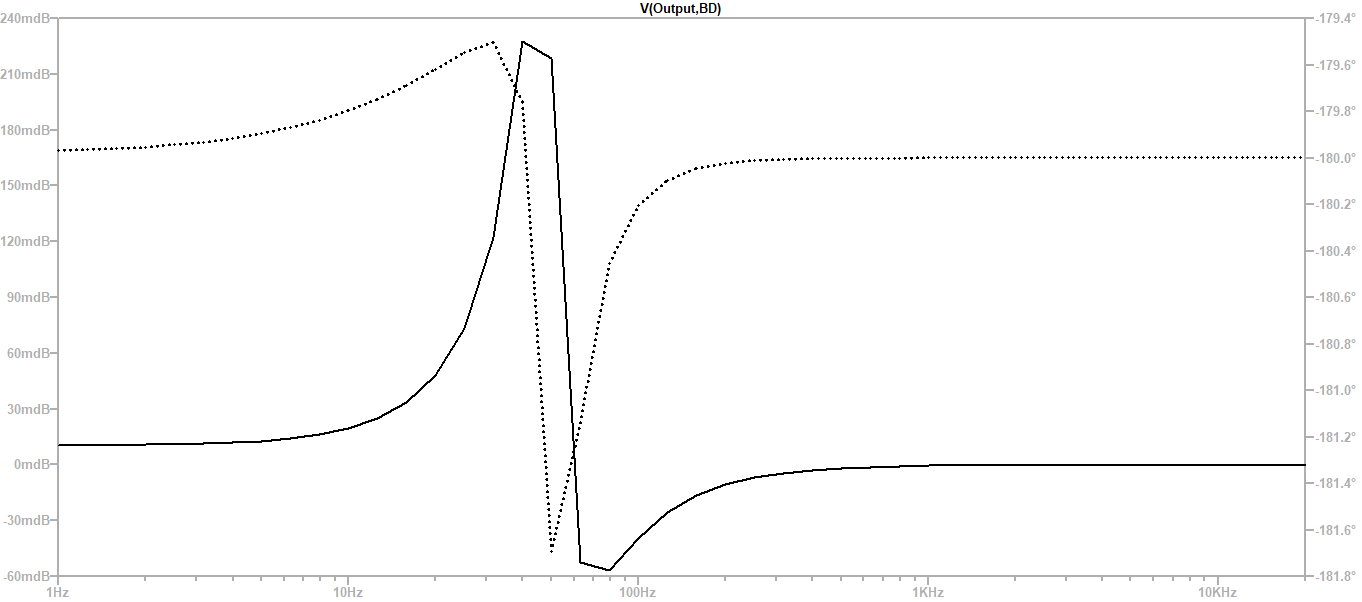
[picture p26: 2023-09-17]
tex/montageanleitung/Images/Übertragungsfunktion Bassdrum.png

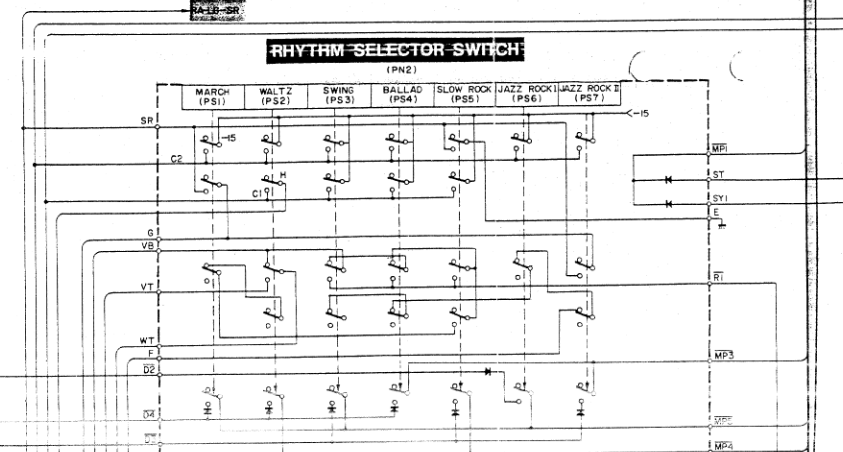
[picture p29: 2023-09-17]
tex/montageanleitung/Images/RhythmSelection.png

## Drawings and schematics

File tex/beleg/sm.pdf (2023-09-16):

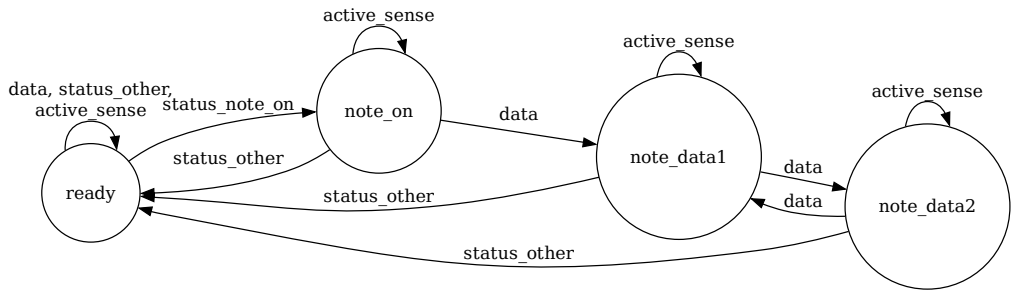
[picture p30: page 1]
ready; data, status_other,; active_sense; note_on status_note_on; status_other; note_data1; data; note_data2

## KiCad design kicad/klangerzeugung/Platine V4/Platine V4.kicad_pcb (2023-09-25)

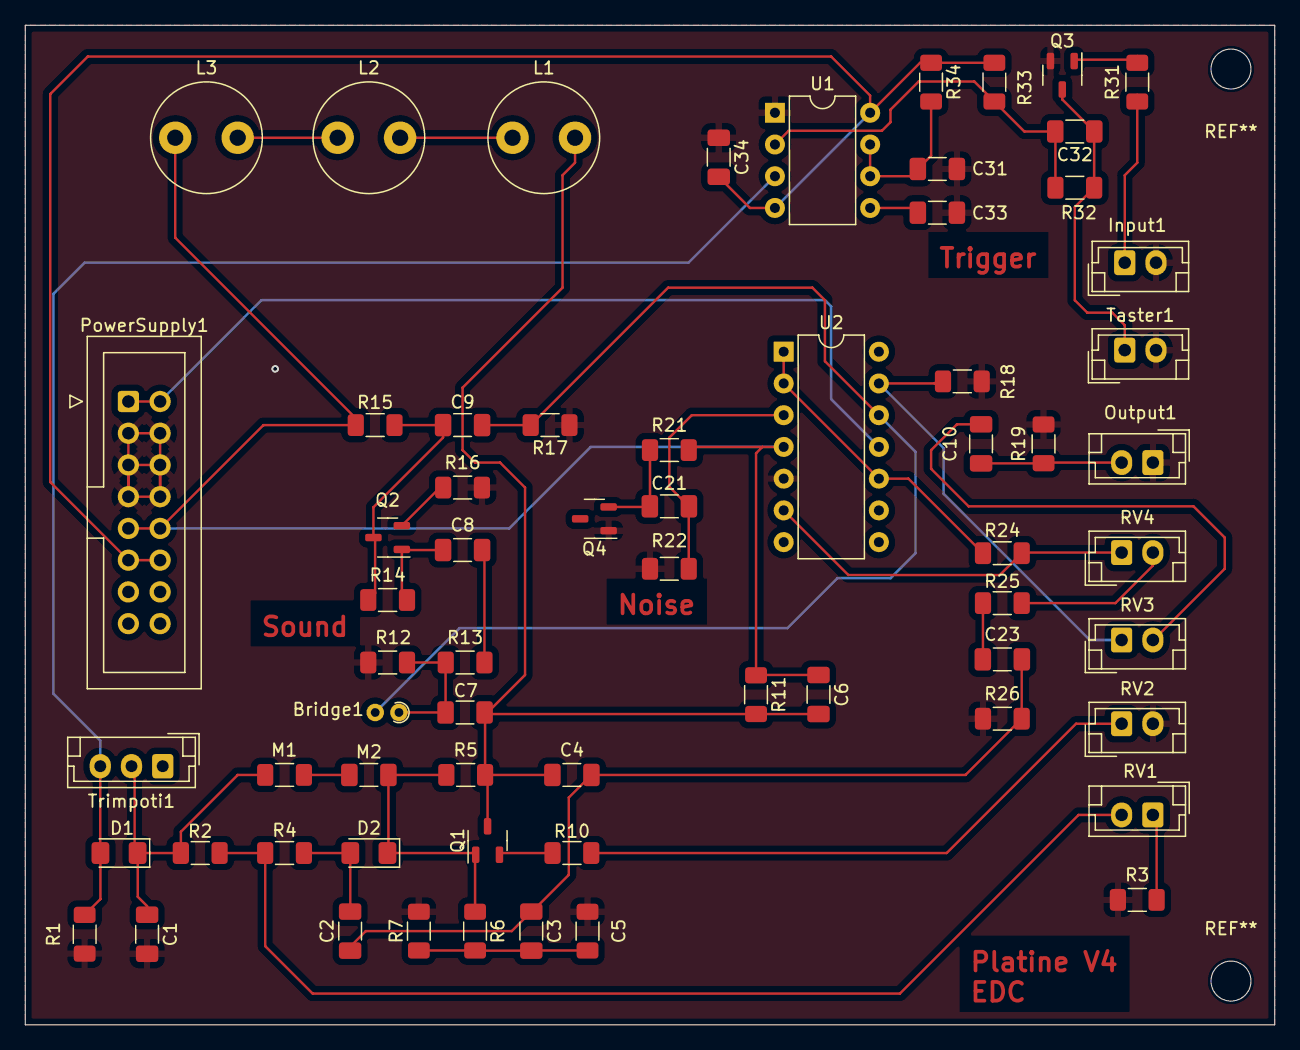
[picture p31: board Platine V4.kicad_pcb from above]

Board: 2 copper layers, 100.0 x 80.0 mm, 65 parts (0 on the bottom side), 39 nets.

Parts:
Bridge1: 0; R_Axial_DIN0204_L3.6mm_D1.6mm_P1.90mm_Vertical
C1: 56n; C_1206_3216Metric_Pad1.33x1.80mm_HandSolder
C2, C4, C32: 10n; C_1206_3216Metric_Pad1.33x1.80mm_HandSolder
C3, C6: 1n; C_1206_3216Metric_Pad1.33x1.80mm_HandSolder
C5: 1000k; R_1206_3216Metric_Pad1.30x1.75mm_HandSolder
C7, C8, C9, C10, C21, C23: 1u; C_1206_3216Metric_Pad1.33x1.80mm_HandSolder
C31, C34: 100n; C_1206_3216Metric_Pad1.33x1.80mm_HandSolder
C33: 10u; C_1206_3216Metric_Pad1.33x1.80mm_HandSolder
D1: D; D_1206_3216Metric_Pad1.42x1.75mm_HandSolder
D2: D2; D_1206_3216Metric_Pad1.42x1.75mm_HandSolder
Input1: Conn_01x02_Pin; JST_EH_B2B-EH-A_1x02_P2.50mm_Vertical
L1, L2, L3: 100m; L_Radial_D8.7mm_P5.00mm_Fastron_07HCP
M1: 1M; R_1206_3216Metric_Pad1.30x1.75mm_HandSolder
M2: 82n; C_1206_3216Metric_Pad1.33x1.80mm_HandSolder
Output1: Conn_01x02_Pin; JST_EH_B2B-EH-A_1x02_P2.50mm_Vertical
PowerSupply1: Conn_02x08_Odd_Even; IDC-Header_2x08_P2.54mm_Vertical
Q1, Q2, Q3, Q4: Q_NPN_BEC; SOT-23-3
R1, R31, R34: 10k; R_1206_3216Metric_Pad1.30x1.75mm_HandSolder
R2, R3, R4, R7, R13, R14: 1000k; R_1206_3216Metric_Pad1.30x1.75mm_HandSolder
R5, R6: 470k; R_1206_3216Metric_Pad1.30x1.75mm_HandSolder
R10: 100; R_1206_3216Metric_Pad1.30x1.75mm_HandSolder
R11, R15: 1.5k; R_1206_3216Metric_Pad1.30x1.75mm_HandSolder
R12, R16, R17: 3k; R_1206_3216Metric_Pad1.30x1.75mm_HandSolder
R18, R19, R24, R26: 1k; R_1206_3216Metric_Pad1.30x1.75mm_HandSolder
R21, R22, R25: 100k; R_1206_3216Metric_Pad1.30x1.75mm_HandSolder
R32: 47k; R_1206_3216Metric_Pad1.30x1.75mm_HandSolder
R33: 220; R_1206_3216Metric_Pad1.30x1.75mm_HandSolder
RV1, RV2, RV4: 10k; JST_EH_B2B-EH-A_1x02_P2.50mm_Vertical
RV3: 50k; JST_EH_B2B-EH-A_1x02_P2.50mm_Vertical
Taster1: Conn_01x02_Pin; JST_EH_B2B-EH-A_1x02_P2.50mm_Vertical
Trimpoti1: 10k; JST_EH_B3B-EH-A_1x03_P2.50mm_Vertical
U1: NE555P; DIP-8_W7.62mm
U2: TL074; DIP-14_W7.62mm

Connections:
+5V: C34.2, PowerSupply1.11, PowerSupply1.12, R33.1, R34.1, U1.4 (R), U1.8 (VCC)
+12V: C6.1, L3.1, PowerSupply1.9, PowerSupply1.10, R11.1, R15.1, R21.1, U2.4 (V+)
-12V: PowerSupply1.1, PowerSupply1.2, U2.11 (V-)
GND: C1.2, C5.2, C31.1, C33.1, C34.1, Input1.2, Output1.1, PowerSupply1.3, PowerSupply1.4, PowerSupply1.5, PowerSupply1.6, PowerSupply1.7, PowerSupply1.8, Q3.2 (E), Q4.1 (B), R1.2, R3.1, R7.2, R12.1, R16.1, R17.1, R18.1, R19.2, R22.2, R26.2, RV2.2, Taster1.2, U1.1 (GND), U2.5 (+)
unnamed: Bridge1.1, C7.2, R12.2, R13.2
unnamed: C2.1, C3.1, C4.1, C23.2, R26.1
unnamed: C3.2, C5.1, R6.2, R7.1
unnamed: C8.1, R13.1
unnamed: C10.1, RV3.2
unnamed: C23.1, R25.2
unnamed: D1.2 (A), R1.1, Trimpoti1.3, U1.3 (Q)
unnamed: C1.1, D1.1 (K), M1.1, R2.1, Trimpoti1.2
unnamed: C2.2, D2.2 (A), R4.2
unnamed: D2.1 (K), M2.2, Q1.1 (B), R5.2, R6.1
unnamed: Input1.1, R31.1
unnamed: L1.1, L2.2
unnamed: L2.1, L3.2
unnamed: M1.2, M2.1
unnamed: C10.2, Output1.2, R19.1
unnamed: C4.2, C6.2, C7.1, L1.2, Q1.3 (C), R5.1, R11.2
unnamed: Q1.2 (E), R10.2
unnamed: C8.2, Q2.1 (B), R14.2
unnamed: C9.1, Q2.3 (C), R14.1, R15.2
unnamed: Q2.2 (E), R16.2
unnamed: Q3.1 (B), R31.2
unnamed: C32.1, Q3.3 (C), R32.2, Taster1.1
unnamed: C21.1, Q4.2 (E), R21.2
unnamed: R2.2, R4.1, RV1.2
unnamed: R3.2, RV1.1
unnamed: R10.1, RV2.1
unnamed: R25.1, RV4.2
unnamed: C33.2, U1.5 (CV)
unnamed: C31.2, R34.2, U1.6 (THR), U1.7 (DIS)
unnamed: C32.2, R32.1, R33.2, U1.2 (TR)
unnamed: C21.2, R22.1, U2.3 (+)
unnamed: R24.1, U2.1, U2.2 (-), U2.10 (+)
unnamed: R24.2, RV4.1, U2.6 (-)
unnamed: Bridge1.2, C9.2, R17.2, U2.12 (+)
unnamed: R18.2, RV3.1, U2.13 (-)

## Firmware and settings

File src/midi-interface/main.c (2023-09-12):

#include "uart.h"
#include <avr/common.h>
#include <stdint.h>
#include <util/atomic.h>
#include <util/delay.h>
#define DATA_REGISTER_EMPTY_INTERRUPT (1 << UDRIE0)

// enums
// enum for the state machine
typedef enum e_sm_state {
  RECV_STATUS_CODE,
  RECV_NOTE_DATA,
  RECV_VELOCITY_DATA
} sm_state;

// enum for possible types of midi packages
typedef enum e_midi_packet_type {
  STATUS_NOTE_ON,
  STATUS_OTHER,
  DATA,
  HEARTBEAT
} midi_packet_type;

// structs
// structure to store a note on message
typedef struct s_midi_note_on_message {
  char note;
  char velocity;
} midi_note_on_message;

// global vars
volatile uint16_t outputs_now;
volatile uint16_t outputs_next;

// functions
// returns the midi packet type of a message
midi_packet_type get_midi_packet_type(uint8_t data) {
  if (data == 0x01)
    return HEARTBEAT;
  if (data <= 0x7f)
    return DATA;
  if (data >= 0x80 && data < 0x90)
    return STATUS_NOTE_ON;
  return STATUS_OTHER;
}
void update_scheduler(midi_note_on_message message) {
  // first output is mapped to c3 at midi note code 60
  uint16_t output = message.note - 60;
  if (output <= 11 && output >= 0) {
    outputs_next |= 0x1 << output;
  }
}

// Fetches new byte from uart
uint8_t get_midi_message() {
  uint8_t buffer = UDR0;
  return buffer;
}

// handles a new midi message
void handle_midi_message() {
  static sm_state state;
  static midi_note_on_message new_note_on_message;
  uint8_t data = get_midi_message();
  midi_packet_type midi_type = get_midi_packet_type(data);
  // midi state machine
  switch (state) {
  case RECV_STATUS_CODE:
    if (midi_type == STATUS_NOTE_ON)
      state = RECV_NOTE_DATA;
    break;

  case RECV_NOTE_DATA:
    if (midi_type == DATA) {
      new_note_on_message.note = data;
      state = RECV_VELOCITY_DATA;
    }
    if (midi_type == STATUS_OTHER)
      state = RECV_STATUS_CODE;
    break;

  case RECV_VELOCITY_DATA:
    if (midi_type == DATA) {
      new_note_on_message.velocity = data;
      update_scheduler(new_note_on_message);
      state = RECV_NOTE_DATA;
    }
    if (midi_type == STATUS_NOTE_ON)
      state = RECV_NOTE_DATA;
    if (midi_type == STATUS_OTHER)
      state = RECV_STATUS_CODE;
    break;
  }
}
void init_gpio() {
  // DDRB |= 0x00111111; // DOUT 8 to 13 are mapped to PORTB 0 to 6 => set them
  // as output
  DDRB |= 0b00111111;

  // DDRD |= 0x11111100; // DOUT 2 to 7 are mapped to PORTD 2 to 7  => set them
  // as OUTPUT
  DDRD |= 0b11111100; // DOUT 2 to 7 are mapped to PORTD 2 to 7  => set them as
  _delay_ms(2);
  PORTB = 0b00000000;
  // set all outputs to 0, set PD0 to tri state
  PORTD = 0b00000000;
  _delay_ms(2);
}
void set_outputs() {
  // Clear all output Pins
  PORTB &= 0b11000000;
  PORTD &= 0b00000011;

  // set ouput pins as needed
  if (outputs_now & (0x1 << 0)) {
    // OUPUT 1 mapped to Port D Pin 5
    PORTD |= (0x1 << 5);
  }
  if (outputs_now & (0x1 << 1)) {
    // OUPUT 2 mapped to Port D Pin 4
    PORTD |= (0x1 << 4);
  }
  if (outputs_now & (0x1 << 2)) {
    // OUPUT 3 mapped to Port D Pin 3
    PORTD |= (0x1 << 3);
  }
  if (outputs_now & (0x1 << 3)) {
    // OUPUT 4 mapped to Port D Pin 2
    PORTD |= (0x1 << 2);
  }
  if (outputs_now & (0x1 << 4)) {
    // OUPUT 5 mapped to Port B Pin 1
    PORTB |= (0x1 << 1);
  }
  if (outputs_now & (0x1 << 5)) {
    // OUPUT 6 mapped to Port B Pin 0
    PORTB |= (0x1 << 0);
  }
  if (outputs_now & (0x1 << 6)) {
    // OUPUT 7 mapped to Port D Pin 7
    PORTD |= (0x1 << 7);
  }
  if (outputs_now & (0x1 << 7)) {
    // OUPUT 8 mapped to Port D Pin 6
    PORTD |= (0x1 << 6);
  }
  if (outputs_now & (0x1 << 8)) {
    // OUPUT 9 mapped to Port B Pin 5
    PORTB |= (0x1 << 5);
  }
  if (outputs_now & (0x1 << 9)) {
    // OUPUT 10 mapped to Port B Pin 4
    PORTB |= (0x1 << 4);
  }
  if (outputs_now & (0x1 << 10)) {
    // OUPUT 12 mapped to Port B Pin 3
    PORTB |= (0x1 << 3);
  }
  if (outputs_now & (0x1 << 11)) {
    // OUPUT 12 mapped to Port B Pin 2
    PORTB |= (0x1 << 2);
  }
}

// Interrupt for received Package -> call handle_midi_message
ISR(USART_RX_vect) { handle_midi_message(); }
int main(void) {
  uart_init();
  init_gpio();
  // enable global interrupts
  sei();
  UCSR0B |= RX_COMPLETE_INTERRUPT;
  while (1) {
    // wait for one ms, then update all outputs
    //
    _delay_ms(1);
    // use atomic block so that we dont have an interrupt messing up our output
    // configuration
    ATOMIC_BLOCK(ATOMIC_FORCEON) {
      outputs_now = outputs_next;
      outputs_next = 0x0;
      set_outputs();
    }
  }
  return 0;
}

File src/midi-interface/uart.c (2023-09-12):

#include "uart.h"
void uart_init() {
  unsigned int prescale = ((F_CPU / (UART_BAUDRATE * 16UL)) - 1);
  // SET BAUD RATE
  // write to lower byte
  UBRR0L = (uint8_t)(prescale & 0xFF);
  // write to higher byte
  UBRR0H = (uint8_t)(prescale >> 8);
  // enable the transmitter and receiver
  UCSR0B |= (1 << RXEN0);
  // Use 8-bit character sizes
  UCSR0C |= (1 << UCSZ00) | (1 << UCSZ01);
}

void uart_putc(char c) {
  // wait for transmit buffer to be empty
  while (!(UCSR0A & (1 << UDRE0)))
    ;
  // load data into transmit register
  UDR0 = c;
}

void uart_puts(char *s) {
  while (*s) {
    uart_putc(*s);
    s++;
  }
}

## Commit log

2023-04-27 kicad midi, ltspice snare
    [midi-interface.kicad_sch]
2023-05-02 midi interface kicad update
    [midi-interface.kicad_pcb, midi-interface.kicad_sch]
2023-05-03 update midi interface layout
    [midi-interface.kicad_pcb, midi-interface.kicad_sch]
2023-05-04 midi interface Platinenlayout, frontplatte
    [frontplatte-midi.scad, frontplatte-midi.stl, midi-interface.kicad_pcb]
2023-05-14 fertiggestellte midi Platine, Frontplatte für midi interface
    [frontplatte-midi.scad, frontplatte-midi.stl, gehäuseabdeckung.scad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]
2023-05-17 gehäuseabdeckung breiter
    [gehäuseabdeckung.stl, gehäuseabdeckung_breiter.scad, gehäuseabdeckung_breiter.stl]
2023-05-17 Simulation der einzelnen Soundsynthesen und Aufteilung der Platinen
2023-05-23 line-out frontplatte
    [frontplatte-line-out.scad, frontplatte-line-out.stl, line-out.kicad_pcb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]
2023-05-31 Erster Platinenentwurf
    Erster Platinenentwurf, ohne Tasterschaltung
    [KiKAD schalter.kicad_pcb, KiKAD schalter.kicad_sch, KiKAD schalter_1.kicad_pcb]
2023-05-31 drummodul schaltplan angepasst
    [KiKAD schalter.kicad_pcb, KiKAD schalter.kicad_sch, KiKAD schalter_1.kicad_pcb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]
2023-06-01 c code
    [gehäuseabdeckung_rückseite.scad]
2023-06-05 Progress in KiCad
    Habe Neue Ordner Erstellt, wo die einzelnen Platinen drin sind. Bisher habe ich alle Schaltungen in KiCad aufgebaut,
    das PlatinenDesign kommt heute Abend
    [KiKAD schalter_1_MitNe555.kicad_sch, KiKAD_Final_Platine_1_V1.kicad_sch, KiKAD_Final_Platine_2_V1.kicad_sch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]
2023-06-06 Platinen sind Ready
    [KiKAD_Final_Platine_1_V1.kicad_pcb, KiKAD_Final_Platine_1_V1.kicad_sch, KiKAD_Final_Platine_2_V1.kicad_pcb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]
2023-06-07 midi src
    [gehäuseabdeckung_rückseite.scad, gehäuseabdeckung_rückseite.stl]
2023-06-20 Platine (unfertig)
    [KiKAD_Endplatine_V1.kicad_sch, KiKAD_Endplatine_V2.kicad_pcb, KiKAD_Endplatine_V2.kicad_sch]
2023-06-23 Platinendesign update mit 2 Induktoren
    [KiKAD_Endplatine_V2.kicad_pcb, KiKAD_Endplatine_V2.kicad_sch]
2023-06-25 Platinenupdate
    Platine geupdatet Beschriftung mehr oder weniger gut
    [KiKAD_Endplatine_V2.kicad_pcb, KiKAD_Endplatine_V2.kicad_sch]
2023-06-27 Schaltplan verschönert
    [KiKAD_Endplatine_V2.kicad_pcb, KiKAD_Endplatine_V2.kicad_sch]
2023-06-28 Namenochmal geupdated
    [KiKAD_Endplatine_V2.kicad_pcb, KiKAD_Endplatine_V2.kicad_sch]
2023-06-28 ultra finales update
    [frontplatte-midi.scad, frontplatte-midi.stl, midi-interface.kicad_pcb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]
2023-06-28 kicad überarbeitung
    [KiKAD_Endplatine_V2.kicad_pcb, KiKAD_Endplatine_V2.kicad_sch]
2023-06-28 noch endgültigere finalplatine
    [KiKAD_Endplatine_V2.kicad_sch]
2023-06-30 PLATINE endlich fertig glaube ich
    [KiKAD_Endplatine_V2.kicad_pcb, KiKAD_Endplatine_V2.kicad_sch]
2023-07-08 Beschriftung verändert
    [KiKAD_Endplatine_V2.kicad_pcb]
2023-08-25 software entwurf 1
    [frontplatte-midi.stl]
2023-09-11 alles mögliche
    [Bauteillliste_E-Reihe.xlsx, KiKAD_Endplatine_V1.kicad_sch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]
2023-09-11 kleines Platinenupdate
    [KiKAD_Endplatine_V2-B_Cu.gbl, KiKAD_Endplatine_V2-B_Mask.gbs, KiKAD_Endplatine_V2-B_Paste.gbp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]
2023-09-12 Sachen gelöscht
    Alte Kicad Projekte gelöscht
    s
    [KiKAD schalter.kicad_pcb, KiKAD schalter.kicad_sch, KiKAD schalter_1.kicad_pcb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]
2023-09-12 diverse scad dateien
    [abstandshalter stromversorgung.scad, abstandshalter stromversorgung.stl, blindplatte_6te.scad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]
2023-09-14 Summierer hinzugefügt
    [summierer.kicad_pcb, summierer.kicad_sch]
2023-09-14 ergänzung summierer
    [summierer.kicad_sch]
2023-09-15 neue beschriftung in KiCad
2023-09-15 Anfang von Bautteilliste
    [Bauteilliste_extended.xlsx]
2023-09-16 3DP Modules
    [modul_2_poti.scad, modul_2_poti.stl, modul_3_poti.scad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]
2023-09-16 Bautteilliste Update
    Neue Bautteilliste jtzt in Doku Ordner
    KiCad Namensstruktur verändert und jaaa
    [Bauteilliste_Klänge.xlsx, Bauteilliste_extended.xlsx, Platine 1 Bauteilliste.xlsx]
2023-09-16 jetzt hoffentlich
    [KiKAD_Endplatine_V2.kicad_pcb, KiKAD_Endplatine_V2.kicad_sch]
2023-09-17 aufgeräumt
    [KiKAD_Endplatine_V2.kicad_pcb, KiKAD_Endplatine_V2.kicad_sch, abstandshalter stromversorgung.scad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]
2023-09-23 Schaltungsplan Update
    Massebezug hergestellt, update zu Footprints
    [Bauteilliste_Klänge.xlsx, KiKAD_Endplatine_V2.kicad_pcb, KiKAD_Endplatine_V2.kicad_sch]
2023-09-23 Update 2 zu Platinen
    [KiKAD_Endplatine_V2.kicad_pcb, KiKAD_Endplatine_V2.kicad_sch]
2023-09-25 Neues Platinendesign
    Neues Platinendesign
    - Angenehmeres Design
    - Drahtbrücken in Schaltung inbegriffen
    - Bessere Footprints
    [Bauteilliste_Klänge.xlsx, KiKAD_Endplatine_V2.kicad_pcb, Platine V4.kicad_pcb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]
2023-09-25 Platinenbeschriftung
    Jetzt auch mit einer Platinen Beschriftung:
    Platine 4
    EDC (EIB DrumComputer)
    [Platine V4.kicad_pcb]
